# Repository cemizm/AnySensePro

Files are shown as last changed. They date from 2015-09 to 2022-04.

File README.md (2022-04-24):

# AnySense Pro
The AnySense Pro (aka 2.0) is an onboard flight logger and real-time telemetry system for (mainly) multicopters with versatile interfacing to various flight controllers, sensors and telemetry protocols. It is a further development of the [AnySense](https://github.com/cemizm/AnySense) and provides a more powerfull MCU (STM32F3) an SD-Card interface and USB connectivity for configuration and updates. A detailed description of the AnySense Pro can be found in the [manual](Dokumentation/AnySense_Pro_EN_.pdf) and in sources of the [main application](Firmware/shared/Application/source).

## Features
The aim of the AnySense Pro is to build a bridge between multiple proprietary systems and protocols in order to reduce the total take-off weight of the flight object. This is achived by reusing any existing sensor (source) of the integrated flight controller in a multicopter, and feeding the telemetry data to various sinks like the onboard SD-Card or real-time telemetrie return channel. 
 
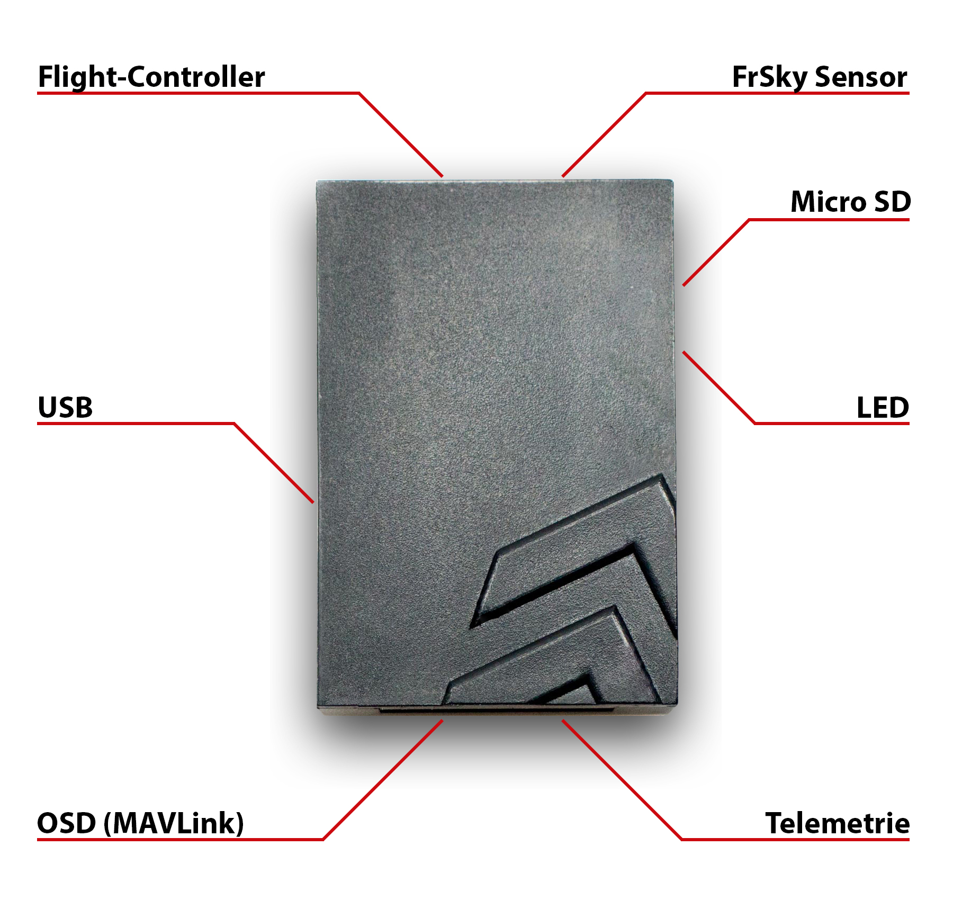
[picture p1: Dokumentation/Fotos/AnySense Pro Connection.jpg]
 

### Flight Controller (source)
The AnySense Pro supports a wide range of open source and commercial flight controllers. A full list of provided sensors of each flight controller can be found in the [Manual](Dokumentation/AnySense_Pro_EN_.pdf). The flight controller connector provides 5V power supply, a CAN-Bus interface and full-duplex uart interface. 

| | |
|:---:|:---:|
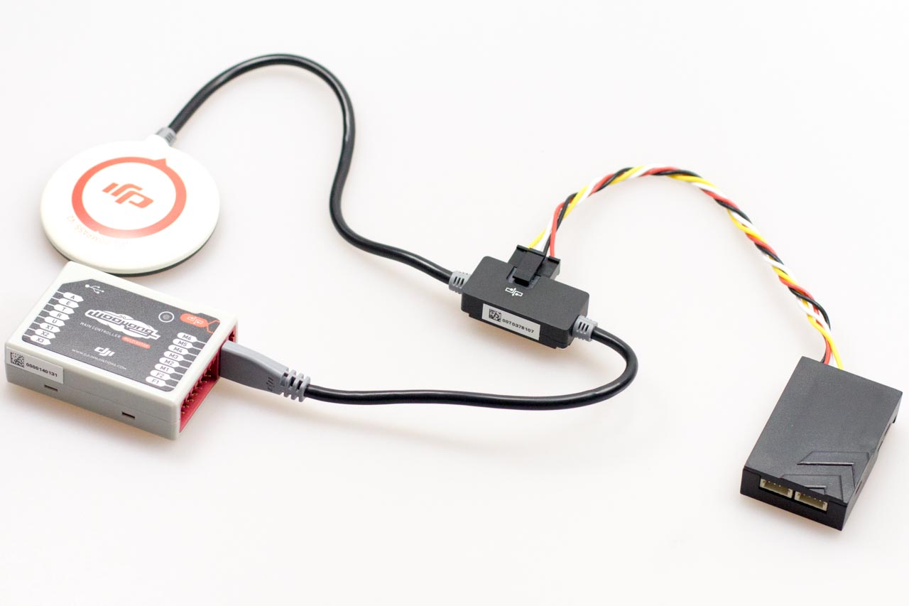
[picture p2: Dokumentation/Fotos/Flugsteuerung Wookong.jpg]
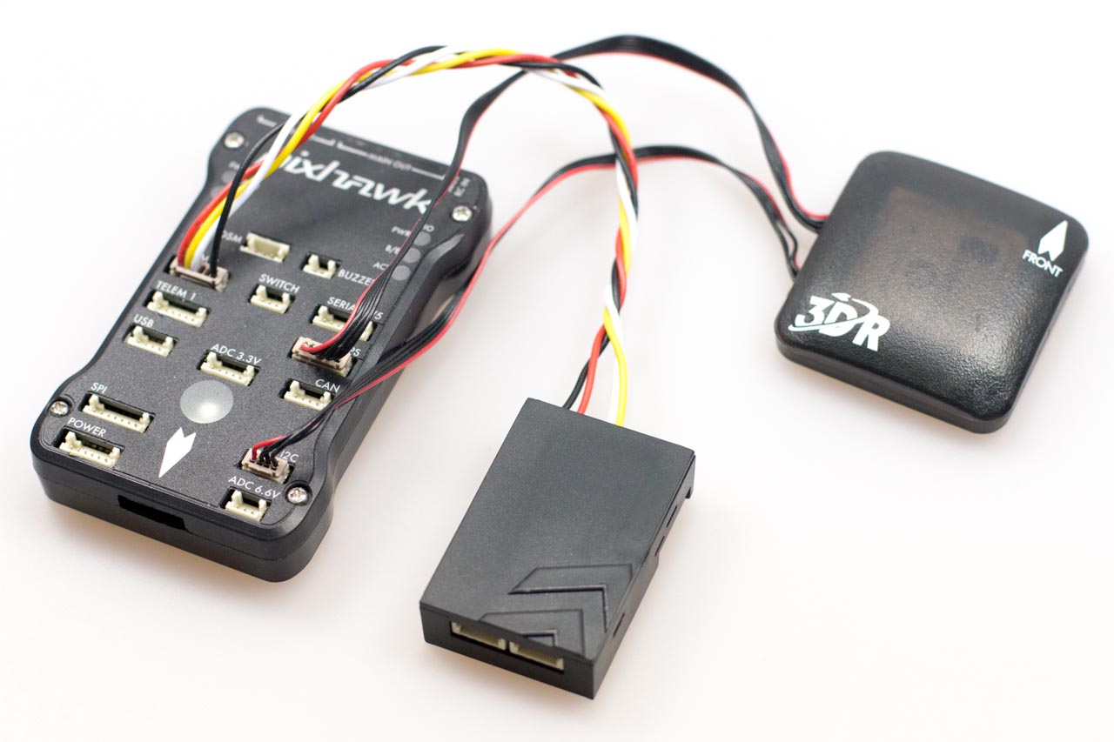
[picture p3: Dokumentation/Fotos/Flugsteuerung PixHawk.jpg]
|  |  |

* [DJI Naza-M V1 / Lite](https://www.dji.com/de/naza-m-lite/feature)
* [DJI Naza-M V2](https://www.dji.com/de/naza-m-v2)
* [DJI Wookong](https://www.dji.com/de/wookong-m)
* [DJI A2](https://www.dji.com/de/a2)
* [DJI Phantom 2](https://www.dji.com/de/phantom-2)
* [3DR Pixhawk](https://docs.px4.io/master/en/flight_controller/mro_pixhawk.html)
* [Tarot ZYX-M](http://www.tarotrc.com/Product/Detail.aspx?Lang=en&Id=65341cc3-7941-4a12-84ea-8abc58bd59e7)
* [Align MRS](https://www.align.com.tw/index.php/download-en/mrs/)

Depending on the flight control, a corresponding cable with connectors and pin assignment is required. The pin assignment defines which hardware interface is used. The pinout of the flight controller connector on the AnySense Pro can be found in the [Schematics](Hardware/Pro/AnySensePro.pdf) or in some [example cables](Hardware/Kabel/CANBusKabel.pdf).

### FrSky Sensor (source)
Additionally to the integrated sensor of the flight controller, it is possible to use sensor of the vendor FrSky to obtain further telemetry data like a current sensor to measure total current consumption or a cell voltage sensor to monitor individual cells of the battery pack. The full list of supported sensors and implementation details can be found in the [source code](Firmware/shared/Application/source/SensorFrSky.cpp).

| | |
|:---:|:---:|
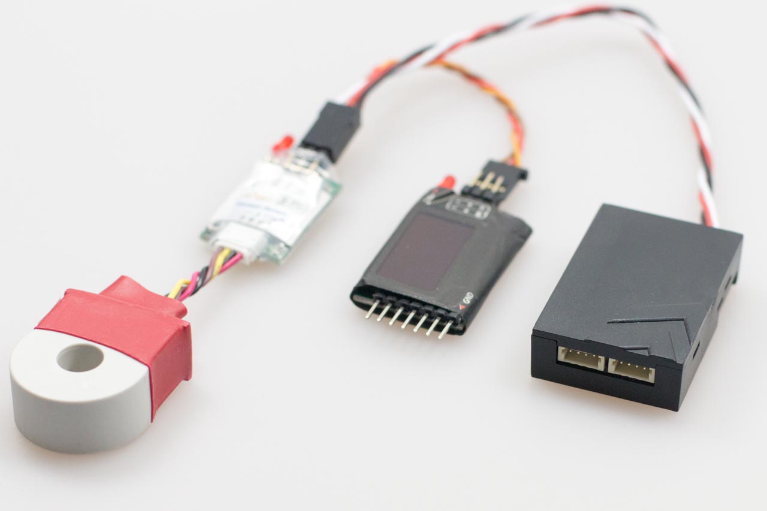
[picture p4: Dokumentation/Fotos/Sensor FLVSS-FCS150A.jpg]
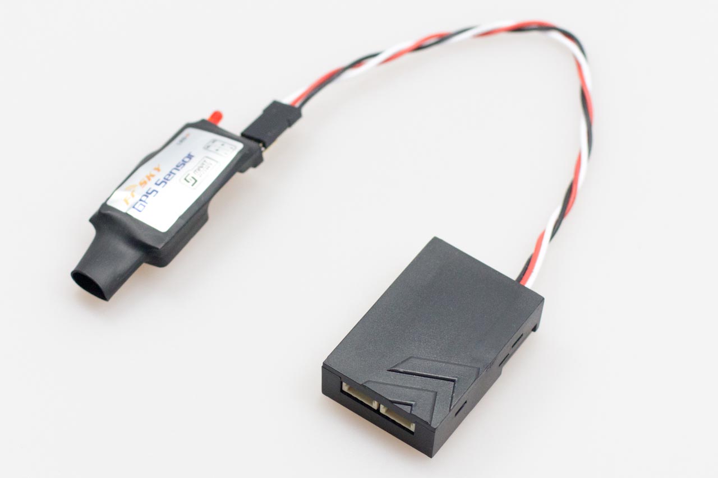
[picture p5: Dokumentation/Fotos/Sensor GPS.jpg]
|  |  |

The FrSky sensors run as a bus system and can therefore be daisy-chained together. for this purpose, each sensor offers two interconnected ports. The AnySense Pro acts as the master and each sensor operates as a slave. 

### USB
The USB interface of the AnySense Pro is used for configuration and firmware updates. The AnySense Pro implements an [USB-CDC device](Firmware/shared/Middleware/USB/source/USBCDCDevice.cpp) for serial communication with the host. The [host driver](Firmware/shared/driver/AnySensePro.inf) for the AnySense Pro uses [Microsoft provided in-box driver](https://docs.microsoft.com/en-us/windows-hardware/drivers/usbcon/usb-driver-installation-based-on-compatible-ids) with custom vendor and product ids. The AnySense Studio is a .NET WPF Application and can be used for configuration and firmware updates.
| | |
|:---:|:---:|
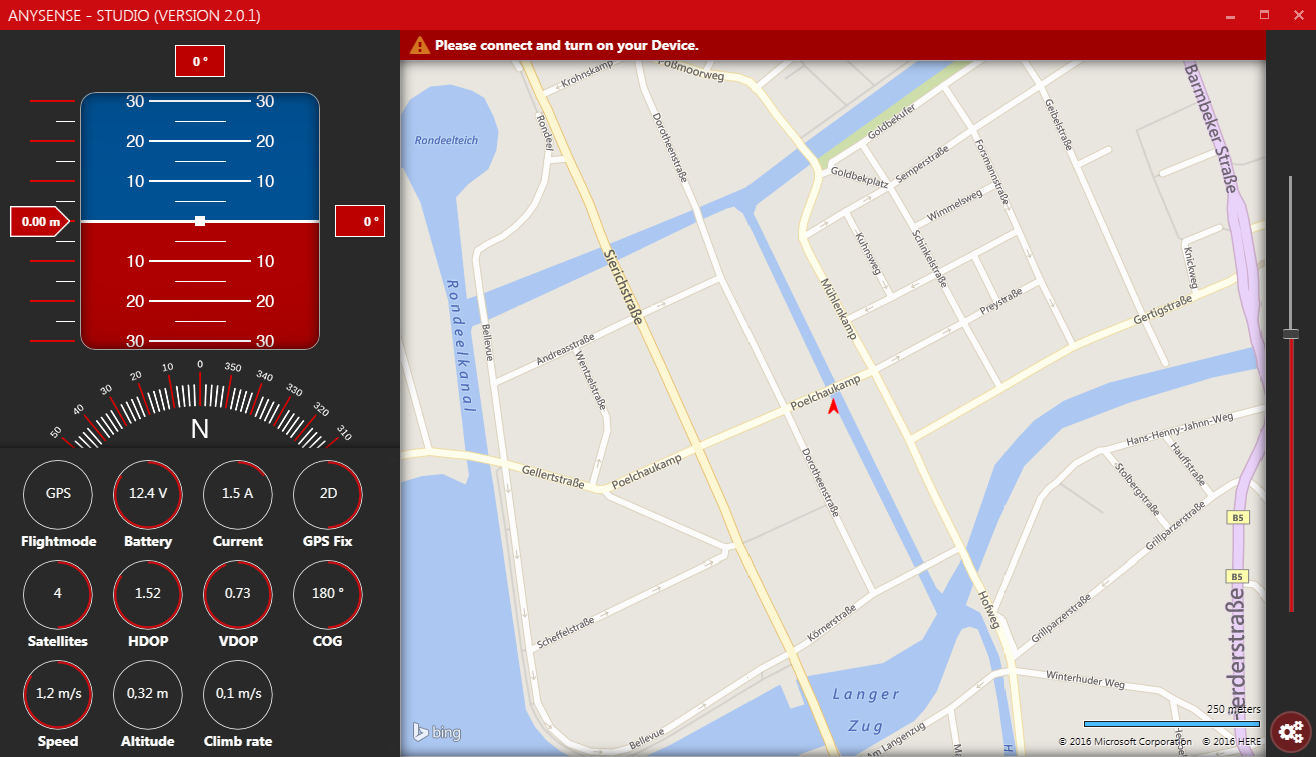
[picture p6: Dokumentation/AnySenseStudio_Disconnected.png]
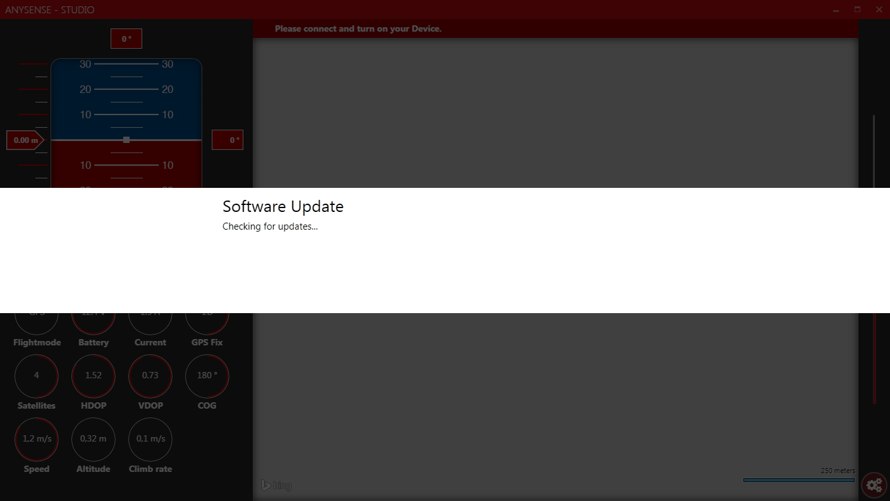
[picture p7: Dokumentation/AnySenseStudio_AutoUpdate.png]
|  |  |

### Micro SD (sink)

### Telemetry (sink)

### MAVLink OSD (sink)

## Project / Repository structure 

### Hardware
### Firmware
### GroundTools
### Dokumnetation

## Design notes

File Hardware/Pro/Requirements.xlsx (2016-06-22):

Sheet: Requirements
Function | IO
DJI | CAN Bus
Konfiguration | USB
Logging | SDIO
Telemetry | USART / I2C
FrSky Sensor | USART
Pixhawk | USART
MAVLink | USART

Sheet: STM32F303RET6
Pin | Name | Function 1 | Function 2 | Function 3 | Function 4
1 | VBAT
2 | PC13
3 | PC14-OSC32_IN
4 | PC15-OSC32_OUT
5 | PF0-OSC_IN | SPI2_NSS | I2C2_SDA |  |  | Function | IO | Mapped
6 | PF1- OSC_OUT | SPI2_SCK | I2C2_SCL |  |  | DJI | CAN Bus | x
7 | NRST |  |  |  |  | Konfiguration | USB | x
8 | PC0 |  |  |  |  | Logging | SPI | x
9 | PC1 |  |  |  |  | Telemetry | USART / I2C | x
10 | PC2 |  |  |  |  | FrSky Sensor | USART
11 | PC3 |  |  |  |  | Pixhawk | USART | x
12 | VSSA |  |  |  |  | MAVLink (OSD) | USART
13 | VDDA |  |  |  |  | Debug | SWD | x
14 | PA0 |  |  |  |  | Extension | i2C | x
15 | PA1 |  |  |  |  | Flash | SPI
16 | PA2 | USART2_TX |  |  |  | Bluetooth | SPI
17 | PA3 | USART2_RX
18 | VSS_4
19 | VDD_4
20 | PA4 | SPI1_NSS | SPI3_NSS
21 | PA5 | SPI1_SCK
22 | PA6 | SPI1_MISO
23 | PA7 | SPI1_MOSI
24 | PC4 | USART1_TX
25 | PC5 | USART1_RX
26 | PB0
27 | PB1
28 | PB2
29 | PB10 | USART3_TX
30 | PB11 | USART3_RX
31 | VSS_2
32 | VDD_2
33 | PB12 | SPI2_NSS
34 | PB13 | SPI2_SCK
35 | PB14 | SPI2_MISO
36 | PB15 | SPI2_MOSI
37 | PC6
38 | PC7
39 | PC8
40 | PC9 |  |  |  | I2C3_ SDA
41 | PA8 |  |  |  | I2C3_ SCL
42 | PA9 | USART1_TX |  |  | I2C2_SCL
43 | PA10 | USART1_RX | SPI2_MISO |  | I2C2_SDA
44 | PA11 | CAN_RX | SPI2_MOSI | USB_DM
45 | PA12 | CAN_TX |  | USB_DP
46 | PA13 | SWDIO-JTMS
47 | VSS_3
48 | VDD_3
49 | PA14 | SWCLK-JTCK | USART2_TX |  | I2C1_SDA
50 | PA15 | SPI1_NSS | USART2_RX | SPI3_NSS | I2C1_SCL
51 | PC10 | UART4_TX | USART3_TX | SPI3_SCK
52 | PC11 | UART4_RX | USART3_RX | SPI3_MISO
53 | PC12 | UART5_TX |  | SPI3_MOSI
54 | PD2 | UART5_RX
55 | PB3 | SPI1_SCK | SPI3_SCK | USART2_TX | JTDO-TRACESWO |  |  |  | uint8_t | 12 | 12
56 | PB4 | SPI1_MISO | SPI3_MISO | USART2_RX |  |  |  |  | float | 13 | 52
57 | PB5 | SPI1_MOSI | SPI3_MOSI |  | I2C3_SDA |  |  |  | double | 4 | 16
58 | PB6 | USART1_TX |  |  | I2C1_SCL |  |  |  | uint16_t | 42 | 84
59 | PB7 | USART1_RX |  |  | I2C1_SDA |  |  |  | uint32_t | 2 | 8
60 | BOOT0 |  |  |  |  |  |  |  |  |  | 172
61 | PB8 | USART3_RX | CAN_RX |  | I2C1_SCL
62 | PB9 | USART3_TX | CAN_TX |  | I2C1_SDA
63 | VSS_1
64 | VDD_1

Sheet: DMA
Channel | SPI | USART | I2C
DMA1_CHANNEL1 |  |  | I2C3_TX
DMA1_CHANNEL2 | SPI1_RX | USART3_TX | I2C3_RX | UART4 (OSD) | TX
DMA1_CHANNEL3 | SPI1_TX | USART3_RX |  | USART2 (FC) | TX,RX
DMA1_CHANNEL4 | SPI2_RX | USART1_TX | I2C2_TX | USART1 (Telemetry) | TX
DMA1_CHANNEL5 | SPI2_TX | USART1_RX | I2C2_RX | I2C2 (Telemetry) | TX
DMA1_CHANNEL6 |  | USART2_RX | I2C1_TX | SPI (MicroSD) | TX,RX
DMA1_CHANNEL7 |  | USART2_TX | I2C1_RX | SPI (Flash) | TX,RX
DMA2_CHANNEL1 | SPI3_RX |  |  | SPI (BLE) | TX,RX
DMA2_CHANNEL2 | SPI3_TX
DMA2_CHANNEL3 |  | UART4_RX
DMA2_CHANNEL4 | SPI4_RX
DMA2_CHANNEL5 | SPI4_TX | UART4_TX |  |  |  | 0 | PackGPS | 50
 |  |  |  |  |  | 1 | PackAttitude | 100
 |  |  |  |  |  | 2 | PackVFRHud | 150
 |  |  |  |  |  | 3 | PackRCOut | 200
 |  |  |  |  |  | 4 | PackAttitude | 250
 |  |  |  |  |  | 5 | PackBatteryPack | 300
 |  |  |  |  |  | 6 | PackHeartbeat | 350
 |  |  |  |  |  | 7 | PackRCOut | 400 | 1
 |  |  |  |  |  | 8 | PackAttitude | 450
 |  |  |  |  |  | 9 | PackSystemStatus | 500

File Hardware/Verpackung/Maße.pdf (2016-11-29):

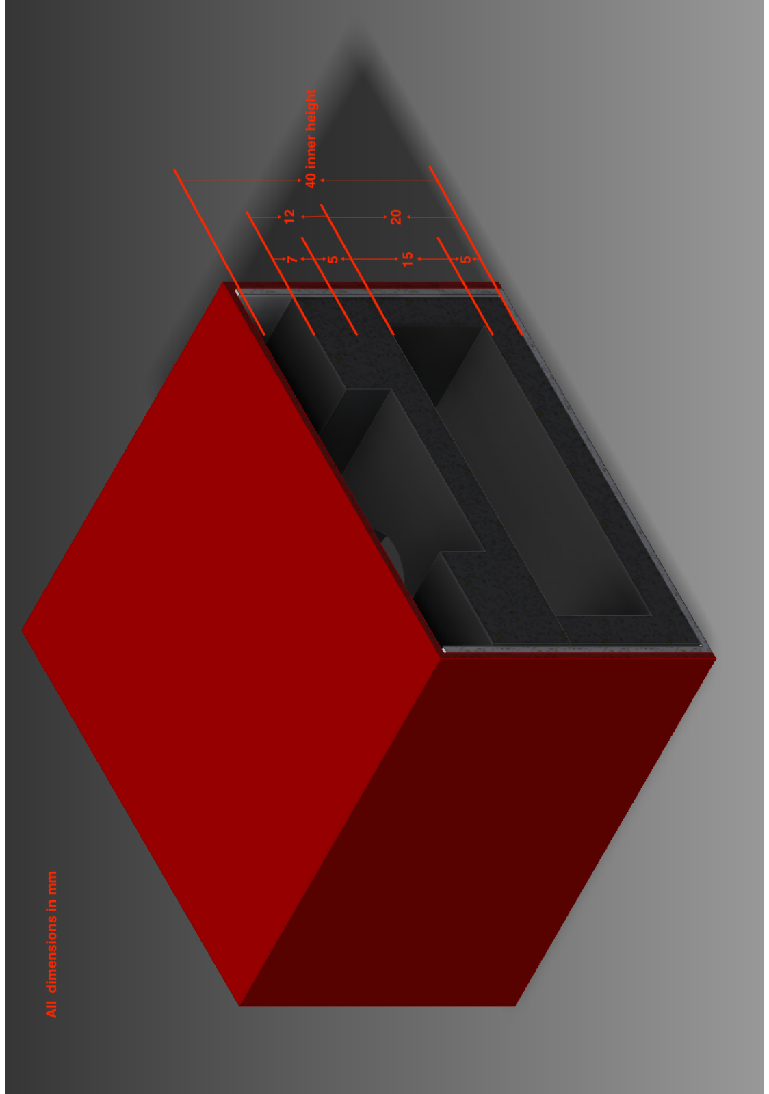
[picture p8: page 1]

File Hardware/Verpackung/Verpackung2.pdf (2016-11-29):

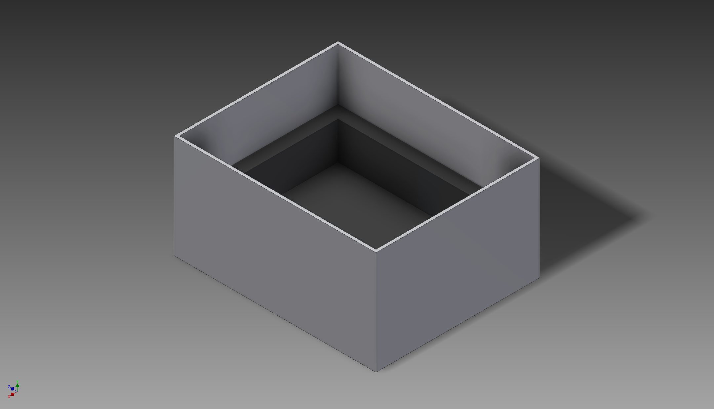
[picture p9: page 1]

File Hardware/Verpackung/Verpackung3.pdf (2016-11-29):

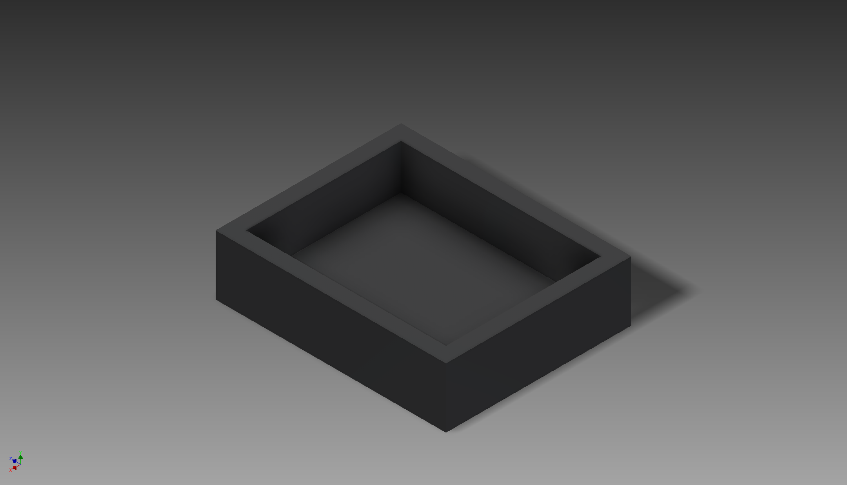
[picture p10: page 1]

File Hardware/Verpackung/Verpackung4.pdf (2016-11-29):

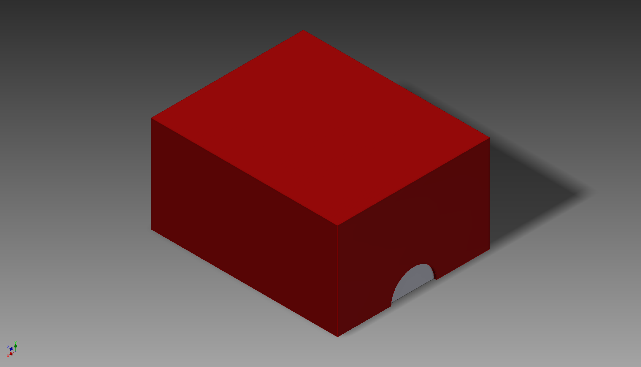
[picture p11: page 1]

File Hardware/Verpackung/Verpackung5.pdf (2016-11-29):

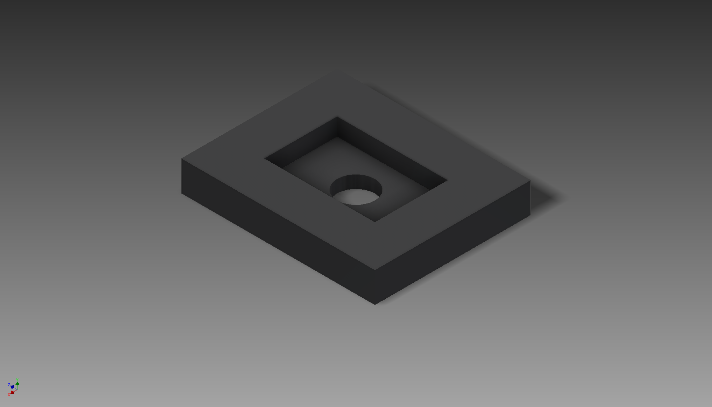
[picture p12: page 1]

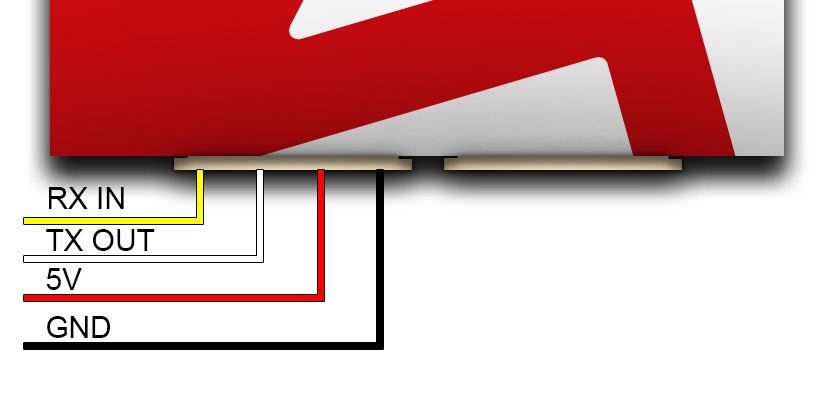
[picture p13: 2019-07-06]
Dokumentation/pinout.png

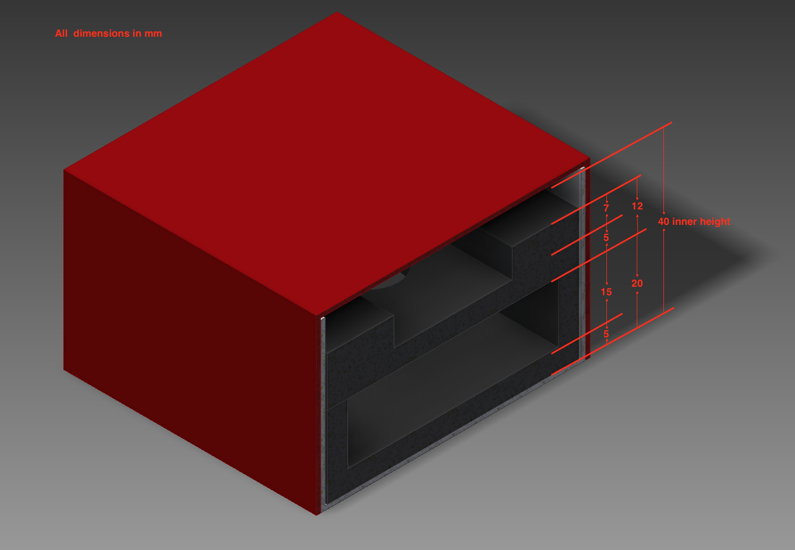
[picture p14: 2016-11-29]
Hardware/Verpackung/Maße.png

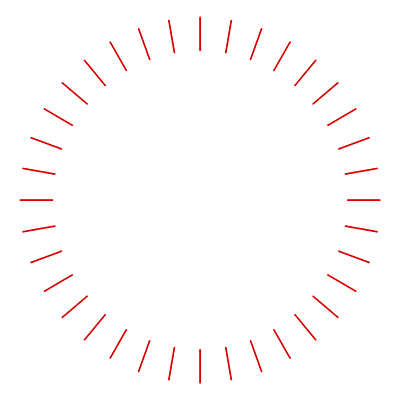
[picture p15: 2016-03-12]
GroundTools/xeniC.AnySense.KonfigurationManager/xeniC.AnySense.Controls/Images/compass.png

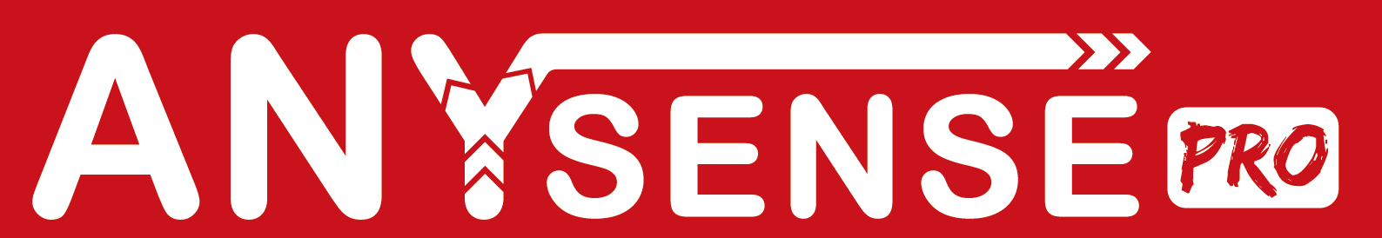
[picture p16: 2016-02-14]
GroundTools/xeniC.AnySense.KonfigurationManager/xeniC.AnySense.KonfigurationManager/Images/AnySense.png

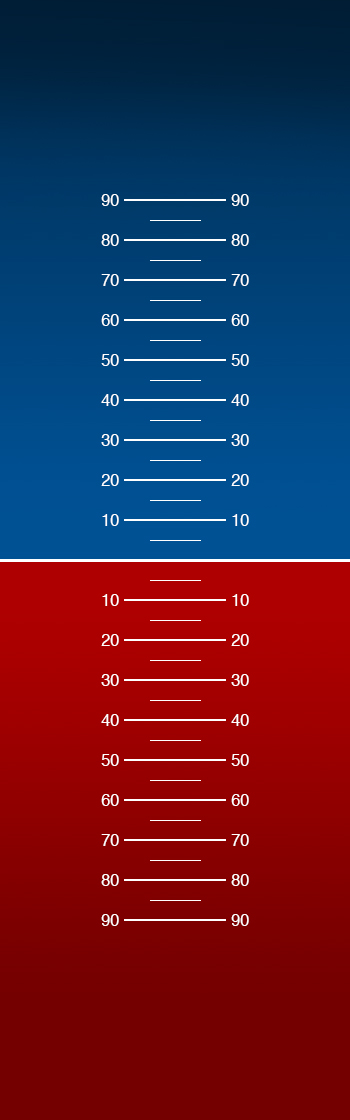
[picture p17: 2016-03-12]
GroundTools/xeniC.AnySense.KonfigurationManager/xeniC.AnySense.Controls/Images/horizon.jpg

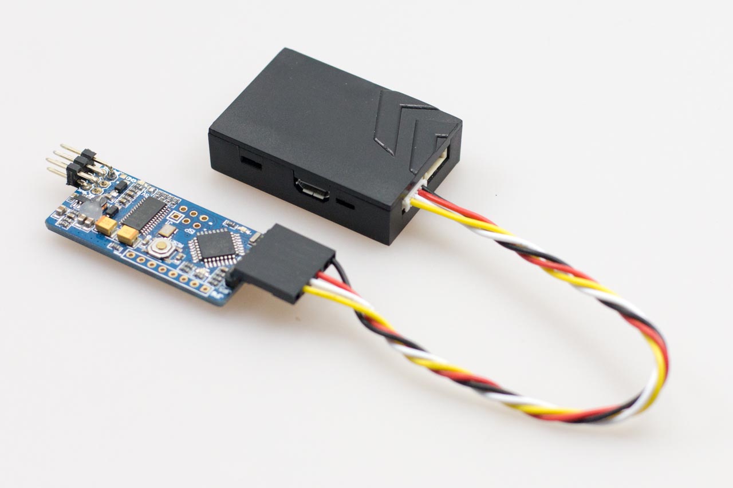
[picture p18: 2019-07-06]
Dokumentation/Fotos/OSD MinimOSD.jpg

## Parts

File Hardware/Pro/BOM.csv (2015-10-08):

Qty | Value | Device | Package | Parts | Description | MPN | OC_FARNELL | OC_NEWARK | PACKAGE | SUPPLIER
1 |  | LEDCHIP-LED0603 | CHIP-LED0603 | P | LED |  | 2468791RL
1 |  | LEDCHIP-LED0603 | CHIP-LED0603 | E | LED |  | 2468792RL
1 |  | LEDCHIP-LED0603 | CHIP-LED0603 | A | LED |  | 2468793RL
1 | 1.5K | R-EU_R0402 | R0402 | R4 | RESISTOR, European symbol |  | 2302739RL
7 | 100nF | C-EUC0402K | C0402K | C8, C12, C14, C15, C16, C30, C31 | CAPACITOR, European symbol |  | 1759380RL
5 | 10K | R-EU_R0402 | R0402 | R3, R5, R9, R10, R12 | RESISTOR, European symbol |  | 2302739RL
2 | 10nF | C-EUC0402K | C0402K | C6, C11 | CAPACITOR, European symbol |  | 1758924RL
1 | 15K | R-EU_R0402 | R0402 | R13 | RESISTOR, European symbol |  | 2302739RL
2 | 18pF | C-EUC0402K | C0402K | C9, C10 | CAPACITOR, European symbol |  | 1758947RL
1 | 1M | R-EU_R0402 | R0402 | R2 | RESISTOR, European symbol |  | 2302957RL
1 | 1uF | C-EUC0402K | C0402K | C7 | CAPACITOR, European symbol |  | 2320776RL
1 | 1uF | C-EUC0603K | C0603K | C1 | CAPACITOR, European symbol |  | 1759409RL
2 | 22R | R-EU_R0402 | R0402 | R1, R11 | RESISTOR, European symbol |  | 2302739RL
2 | 4.7uF | C-EUC0603K | C0603K | C13, C18 | CAPACITOR, European symbol |  | 2320818RL
3 | 820 | R-EU_R0402 | R0402 | R6, R7, R8 | RESISTOR, European symbol |  | 2302628RL
1 | ABM3B | ABM3B-8.000MHZ-B2-T | 5X3.2MM | Y1 |  |  | 2467818RL
2 | BAT721C | BAT721C | SOT23 | D1, D2 | Schottky Diodes |  | 1081199RL
1 | LP2992IM5-3.3 | LP2992IM5-3.3 | SOT-23 | U1 | Low-Dropout Regulator | LP2992IM5-3.3 | 1469141RL
1 | M25P16VMN6P | M25P16VMN6P | M25P16 | U6 |  |  | 1734973
1 | MEM2051-00-195-00-A | MEM2051-00-195-00-A | MEM2051 | X6 | GLOBAL CONNECTOR TECHNOLOGY MEM2051-00-195-00-A STECKPLATZ, MICRO-SD, 8POS, SMTHersteller: GLOBAL CONNECTOR TECHNOLOGYBestellnummer: 2443092Herstellerteilenummer: MEM2051-00-195-00-A |  | 2443092
3 | SM4B-ZR | SM4B-ZR | S4B-ZR-SM4 | OSD, SENSOR, TELEM | ZH Connector: 1.5mm pitch/Disconnectable Crimp style connector |  | 1830923
1 | SN65HVD232D | SN65HVD232D | SOIC127P600X175-8N | U3 | 3.3-V CAN TRANSCEIVERS | SN65HVD232D | 1103107 | 35K4890 | SOIC-8 | Texas Instruments
1 | STM32F303RET6 | STM32F303RET6 | LQFP64 | U4 | ARM® Cortex®-M4 32b MCU+FPU, up to 512KB Flash, 80KB SRAM, FMC, 4 ADCs, 2 DAC ch., 7 comp, 4 Op-Amp, 2.0-3.6 V |  | 2466939
1 | TC2030-IDC-NL | TC2030-IDC-NL | TC2030-IDC | X7
1 | X8B-ZR-SM4 | X8B-ZR-SM4 | S8B-ZR-SM4 | FC | JST ZH Connector |  | 1830925
1 | ZX62R-B-5PA(11) | ZX62R-B-5PA(11) | ZX62R-B-5PA(11) | USB | Micro USB Connector |  | 1645325

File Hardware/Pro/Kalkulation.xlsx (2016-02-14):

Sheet: Stückliste Proto
 |  |  |  |  |  |  | ab | 200 | Stück |  | ab | 500 | Stück
Qty | Farnell | Value | Device | Package | Parts | Description | Menge | Einzelpreis | Positionspreis | ohne BLE | Menge2 | Einzelpreis2 | Positionspreis2 | ohne BLE2 | Link
1 | 2468791RL |  | LEDCHIP-LED0603 | CHIP-LED0603 | P | LED, GRÜN, 3MCD, 570NM, SMD | 200 | 0.0764 € | 15.28 € | 15.28 € | 500 | 0.0634 € | 31.70 € | 31.70 € | Details
1 | 2468792RL |  | LEDCHIP-LED0603 | CHIP-LED0603 | E | LED, ROT, 22MCD, 630NM, SMD | 200 | 0.0712 € | 14.24 € | 14.24 € | 500 | 0.0585 € | 29.25 € | 29.25 € | Details
1 | 2468793RL |  | LEDCHIP-LED0603 | CHIP-LED0603 | A | LED, GELB, 10MCD, 590NM, SMD | 200 | 0.0712 € | 14.24 € | 14.24 € | 500 | 0.0585 € | 29.25 € | 29.25 € | Details
12 | 1759380RL | 100nF | C-EUC0402K | C0402K | C4, C5, C8, C12, C14, C15, C16, C23, C27, C29, C30, C31 | Keramikvielschichtkondensator, SMD, Baureihe MC, 0.1 µF, ± 10%, X5R, 10 V | 2400 | 0.0050 € | 12.00 € | 12.00 € | 6000 | 0.0020 € | 12.00 € | 12.00 € | Details
2 | 2320762RL | 100pF | C-EUC0402K | C0402K | C3, C24 | Keramikvielschichtkondensator, SMD, Baureihe MC, 100 pF, ± 10%, C0G / NP0, 50 V | 400 | 0.0060 € | 2.40 € |  | 1000 | 0.0050 € | 5.00 € |  | Details
6 | 2302739RL | 10K | R-EU_R0402 | R0402 | R1, R3, R4, R5, R9, R10 | Dickschichtwiderstand, Oberflächenmont., Baureihe AEC-Q200 ERJ, 10 kohm, 100 mW, ± 1%, 50 V | 1200 | 0.0069 € | 8.28 € | 8.28 € | 3000 | 0.0059 € | 17.70 € | 17.70 € | Details
2 | 1758924RL | 10nF | C-EUC0402K | C0402K | C6, C11 | Keramikvielschichtkondensator, SMD, Baureihe MC, 0.01 µF, ± 10%, X7R, 25 V | 400 | 0.0070 € | 2.80 € | 2.80 € | 1000 | 0.0060 € | 6.00 € | 6.00 € | Details
1 | 2470467RL | 150nF | C-EUC0402K | C0402K | C25 | Keramikvielschichtkondensator, SMD, Baureihe GRM, 0.15 µF, ± 10%, X7R, 16 V | 200 | 0.0278 € | 5.56 € |  | 500 | 0.0181 € | 9.05 € |  | Details
2 | 1758945RL | 15pF | C-EUC0402K | C0402K | C17, C19 | Keramikvielschichtkondensator, SMD, Baureihe MC, 15 pF, ± 5%, C0G / NP0, 50 V | 400 | 0.0060 € | 2.40 € |  | 1000 | 0.0050 € | 5.00 € |  | Details
2 | 1758947RL | 18pF | C-EUC0402K | C0402K | C9, C10 | Keramikvielschichtkondensator, SMD, Baureihe MC, 18 pF, ± 5%, C0G / NP0, 50 V | 400 | 0.0060 € | 2.40 € | 2.40 € | 1000 | 0.0050 € | 5.00 € | 5.00 € | Details
1 | 2302957RL | 1M | R-EU_R0402 | R0402 | R2 | Dickschichtwiderstand, Oberflächenmont., Baureihe AEC-Q200 ERJ, 1 Mohm, 100 mW, ± 1%, 50 V | 200 | 0.0104 € | 2.08 € |  | 500 | 0.0069 € | 3.45 € |  | Details
6 | 2362093RL | 1uF | C-EUC0402K | C0402K | C1, C2, C7, C22, C26, C28 | Keramikvielschichtkondensator, SMD, Baureihe GRM, 1 µF, ± 10%, X5R, 16 V, 0402 | 1200 | 0.0212 € | 25.44 € |  | 3000 | 0.0149 € | 44.70 € |  | Details
2 | 1758951RL | 22pF | C-EUC0402K | C0402K | C20, C21 | Keramikvielschichtkondensator, SMD, Baureihe MC, 22 pF, ± 5%, C0G / NP0, 50 V | 400 | 0.0060 € | 2.40 € |  | 1000 | 0.0050 € | 5.00 € |  | Details
1 | 1885496RL | 2450AT18A100 | 2450AT18A100 | 2450AT18A100E | A1 | JOHANSON TECHNOLOGY 2450AT18A100E ANTENNE, KERAMIK, 2.45GHZ | 200 | 0.3190 € | 63.80 € |  | 500 | 0.2850 € | 142.50 € |  | Details
2 | 2426952RL | 4.7uF | C-EUC0402K | C0402K | C13, C18 | Keramikvielschichtkondensator, SMD, Baureihe GRM, 4.7 µF, ± 20%, X5R, 6.3 V | 400 | 0.0816 € | 32.64 € | 32.64 € | 1000 | 0.0576 € | 57.60 € | 57.60 € | Details
3 | 2302628RL | 820 | R-EU_R0402 | R0402 | R6, R7, R8 | Dickschichtwiderstand, Oberflächenmont., Baureihe AEC-Q200 ERJ, 820 ohm, 100 mW, ± 1%, 50 V | 600 | 0.0069 € | 4.14 € | 4.14 € | 1500 | 0.0069 € | 10.35 € | 10.35 € | Details
1 | 2467818RL | ABM3B | ABM3B-8.000MHZ-B2-T | 5X3.2MM | Y1 | CRYSTAL, 8MHZ, 18PF, 5 X 3.2MM | 200 | 0.6740 € | 134.80 € | 134.80 € | 500 | 0.5980 € | 299.00 € | 299.00 € | Details
1 | 2467830RL | ABM8 | ABM8-16.000MHZ-10-1-U-T | 3.2X2.5MM | Y2 | QUARZ, 16MHZ, 10PF, 3.2 X 2.5MM | 200 | 0.6360 € | 127.20 € |  | 500 | 0.5730 € | 286.50 € |  | Details
1 | 2467865RL | ABS07 | ABS.ABS07 | ABS07 | Y3 | QUARZ, 32.768KHZ, 12.5PF, 3.2 X 1.5MM | 200 | 0.7890 € | 157.80 € |  | 500 | 0.7120 € | 356.00 € |  | Details
1 | 2454731RL | BALF-NRG-01D3 | BALF-NRG-01D3 | BALF-NRG-01D3 | U5 | FILTER, MATCH, BLUETOOTH, 2.4GHZ-2.5GHZ | 200 | 0.2200 € | 44.00 € |  | 500 | 0.1790 € | 89.50 € |  | Details
2 | 1081199RL | BAT721C | BAT721C | SOT23 | D1, D2 | Kleinsignal-Schottky-Diode, Zweifach, gemeinsame Kathode, 40 V, 200 mA, 300 mV, 1 A, 125 °C | 400 | 0.0773 € | 30.92 € | 30.92 € | 1000 | 0.0751 € | 75.10 € | 75.10 € | Details
1 | 2460183RL | BLUENRGQTR | BLUENRGQTR | QFN32 | U2 | HF-TRANSCEIVER, 2.4835GHZ-2.4GHZ, QFN-32 | 200 | 2.5100 € | 502.00 € |  | 500 | 1.9700 € | 985.00 € |  | Details
1 | 1469141RL | LP2992IM5-3.3 | LP2992IM5-3.3 | SOT-23 | U1 | SPANNUNGSREGLER,LINEAR, 3.3V,SMD | 200 | 0.5830 € | 116.60 € | 116.60 € | 500 | 0.4850 € | 242.50 € | 242.50 € | Details
1 | 1734973 | M25P16VMN6P | M25P16VMN6P | M25P16 | U6 | SPEICHER, FLASH, SERIAL, 16MBIT, 8NSOIC | 200 | 0.8150 € | 163.00 € | 163.00 € | 500 | 0.7020 € | 351.00 € | 351.00 € | Details
1 | 2443092 | MEM2051-00-195-00-A | MEM2051-00-195-00-A | MEM2051 | X6 | STECKPLATZ, MICRO-SD, 8POS, SMT | 200 | 0.8040 € | 160.80 € | 160.80 € | 500 | 0.6720 € | 336.00 € | 336.00 € | Details
3 | 1830923 | SM4B-ZR | SM4B-ZR | S4B-ZR-SM4 | OSD, SENSOR, TELEMETRY | STECKER,ZH,SIDE,4KONT,1.5MM,SMT | 600 | 0.2610 € | 156.60 € | 156.60 € | 1500 | 0.2360 € | 354.00 € | 354.00 € | Details
1 | 1103107 | SN65HVD232D | SN65HVD232D | SOIC127P600X175-8N | U3 | CAN-Bus, Transceiver, CAN, 1, 1, 3 V, 3.6 V, SOIC | 200 | 1.2200 € | 244.00 € | 244.00 € | 500 | 0.8660 € | 433.00 € | 433.00 € | Details
1 | 2466939 | STM32F303RET6 | STM32F303RET6 | LQFP64 | U4 | MCU, 32BIT, CORTEX-M4, 72MHZ, LQFP-64 | 200 | 5.7900 € | 1158.00 € | 1158.00 € | 500 | 4.8700 € | 2435.00 € | 2435.00 € | Details
1 |  | TC2030-IDC-NL | TC2030-IDC-NL | TC2030-IDC | X7 |  | 200 |  | 0.00 € | 0.00 € | 500 |  | 0.00 € | 0.00 € | Details
1 | 1830925 | X8B-ZR-SM4 | X8B-ZR-SM4 | S8B-ZR-SM4 | FC | STECKER,ZH,SIDE,8KONT,1.5MM,SMT | 200 | 0.7350 € | 147.00 € | 147.00 € | 500 | 0.4880 € | 244.00 € | 244.00 € | Details
1 | 1645325 | ZX62R-B-5PA(11) | ZX62R-B-5PA(11) | ZX62R-B-5PA(11) | USB | MICRO USB 2.0 BUCHSE, TYP B, SMD | 200 | 0.4060 € | 81.20 € | 81.20 € | 500 | 0.3620 € | 181.00 € | 181.00 € | Details
Ergebnis |  |  |  |  |  |  |  | 17.1701 | 3434.02 € | 12.49 € |  | 14.1623 | 7081.15 € | 10.30 € | 0.0514945

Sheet: Stückliste Proto2
Kleinteile |  |  |  |  |  |  | Ab | 200 |  | ab | 500
Qty | Farnell | Value | Package | Parts | Description | Link | Anzahl | EP | Summe | Offen | Anzahl2 | EP2 | Summe2 | Offen2
1 | 2468791RL |  | CHIP-LED0603 | P | LED Green | Details | 200 | 0.0634 € | 12.68 € |  | 500 | 0.0634 € | 31.70 €
1 | 2468792RL |  | CHIP-LED0603 | E | LED Red | Details | 200 | 0.0585 € | 11.70 € |  | 500 | 0.0585 € | 29.25 €
1 | 2468793RL |  | CHIP-LED0603 | A | LED Orange | Details | 200 | 0.0585 € | 11.70 € |  | 500 | 0.0585 € | 29.25 €
1 | 2302656RL | 1.5K | R0402 | R4 | Dickschichtwiderstand, Oberflächenmont., Baureihe AEC-Q200 ERJ, 1.5 kohm, 100 mW, ± 1%, 50 V | Details | 200 | 0.0069 € | 1.38 € |  | 500 | 0.0069 € | 3.45 €
7 | 1759380RL | 100nF | C0402K | C8, C12, C14, C15, C16, C30, C31 | Keramikvielschichtkondensator, SMD, Baureihe MC, 0.1 µF, ± 10%, X5R, 10 V | Details | 1400 | 0.0020 € | 2.80 € |  | 3500 | 0.0020 € | 7.00 €
5 | 2302739RL | 10K | R0402 | R3, R5, R9, R10, R12 | Dickschichtwiderstand, Oberflächenmont., Baureihe AEC-Q200 ERJ, 10 kohm, 100 mW, ± 1%, 50 V | Details | 1000 | 0.0059 € | 5.90 € |  | 2500 | 0.0059 € | 14.75 €
2 | 1758924RL | 10nF | C0402K | C6, C11 | Keramikvielschichtkondensator, SMD, Baureihe MC, 0.01 µF, ± 10%, X7R, 25 V | Details | 400 | 0.0060 € | 2.40 € |  | 1000 | 0.0060 € | 6.00 €
1 | 2302754RL | 15K | R0402 | R13 | Dickschichtwiderstand, Oberflächenmont., Baureihe AEC-Q200 ERJ, 15 kohm, 100 mW, ± 1%, 50 V | Details | 200 | 0.0050 € | 1.00 € |  | 500 | 0.0050 € | 2.50 €
2 | 1758947RL | 18pF | C0402K | C9, C10 | Keramikvielschichtkondensator, SMD, Baureihe MC, 18 pF, ± 5%, C0G / NP0, 50 V | Details | 400 | 0.0050 € | 2.00 € |  | 1000 | 0.0050 € | 5.00 €
1 | 2302957RL | 1M | R0402 | R2 | Dickschichtwiderstand, Oberflächenmont., Baureihe AEC-Q200 ERJ, 1 Mohm, 100 mW, ± 1%, 50 V | Details | 200 | 0.0069 € | 1.38 € |  | 500 | 0.0069 € | 3.45 €
1 | 2320776RL | 1uF | C0402K | C7 | Keramikvielschichtkondensator, SMD, Baureihe MC, 1 µF, ± 10%, X5R, 10 V | Details | 200 | 0.0140 € | 2.80 € |  | 500 | 0.0140 € | 7.00 €
1 | 1759409RL | 1uF | C0603K | C1 | Keramikvielschichtkondensator, SMD, Baureihe MC, 1 µF, ± 10%, X5R, 25 V | Details | 200 | 0.0170 € | 3.40 € |  | 500 | 0.0170 € | 8.50 €
2 | 2302453RL | 22R | R0402 | R1, R11 | Dickschichtwiderstand, Oberflächenmont., Baureihe AEC-Q200 ERJ, 22 ohm, 100 mW, ± 1%, 50 V | Details | 400 | 0.0069 € | 2.76 € |  | 1000 | 0.0069 € | 6.90 €
2 | 2320818RL | 4.7uF | C0603K | C13, C18 | Keramikvielschichtkondensator, SMD, Baureihe MC, 4.7 µF, ± 10%, X5R, 10 V | Details | 400 | 0.0440 € | 17.60 € |  | 1000 | 0.0440 € | 44.00 €
3 | 2302628RL | 820R | R0402 | R6, R7, R8 | Dickschichtwiderstand, Oberflächenmont., Baureihe AEC-Q200 ERJ, 820 ohm, 100 mW, ± 1%, 50 V | Details | 600 | 0.0069 € | 4.14 € |  | 1500 | 0.0069 € | 10.35 €
1 | 2467818RL | ABM3B | 5X3.2MM | Y1 | CRYSTAL, 8MHZ, 18PF, 5 X 3.2MM | Details | 200 | 0.5980 € | 119.60 € |  | 500 | 0.5980 € | 299.00 €
2 | 1081199RL | BAT721C | SOT23 | D1, D2 | Kleinsignal-Schottky-Diode, Zweifach, gemeinsame Kathode, 40 V, 200 mA, 300 mV, 1 A, 125 °C | Details | 400 | 0.0751 € | 30.04 € |  | 1000 | 0.0751 € | 75.10 €
 |  |  |  |  |  |  |  | 1.1664 | 233.28 € |  |  | 1.17 € | 583.20 €
Bauteile
Qty | Farnell | Value | Package | Parts | Description | Link | Anzahl | EP | Summe | Offen | Anzahl2 | EP2 | Summe2 | Offen2
1 | 1469141RL | LP2992IM5-3.3 | SOT-23 | U1 | SPANNUNGSREGLER,LINEAR, 3.3V,SMD | Details | 200 | 0.4850 € | 97.00 € |  | 500 | 0.4850 € | 242.50 €
1 | 1734973 | M25P16VMN6P | M25P16 | U6 | SPEICHER, FLASH, SERIAL, 16MBIT, 8NSOIC | Details | 200 | 0.7020 € | 140.40 € |  | 500 | 0.7020 € | 351.00 €
1 | 2443092 | MEM2051-00-195-00-A | MEM2051 | X6 | STECKPLATZ, MICRO-SD, 8POS, SMT | Details | 200 | 0.6720 € | 134.40 € |  | 500 | 0.6720 € | 336.00 €
1 | 1103107 | SN65HVD232D | SOIC127P600X175-8N | U3 | CAN-Bus, Transceiver, CAN, 1, 1, 3 V, 3.6 V, SOIC | Details | 200 | 0.8660 € | 173.20 € |  | 500 | 0.8660 € | 433.00 €
1 | 2466939 | STM32F303RET6 | LQFP64 | U4 | MCU, 32BIT, CORTEX-M4, 72MHZ, LQFP-64 | Details | 200 | 4.8700 € | 974.00 € | 214.28 € | 500 | 4.8700 € | 2435.00 €
1 | 1645325 | ZX62R-B-5PA(11) | ZX62R-B-5PA(11) | USB | MICRO USB 2.0 BUCHSE, TYP B, SMD | Details | 200 | 0.3620 € | 72.40 € |  | 500 | 0.3620 € | 181.00 €
3 |  | SM4B-ZR | S4B-ZR-SM4 | OSD, SENSOR, TELEM | STECKER,ZH,SIDE,4KONT,1.5MM,SMT | Details | 600 | 0.0550 € | 33.00 € |  | 1500 | 0.0550 € | 82.50 €
1 |  | S8B-ZR-SM4 | S8B-ZR-SM4 | FC | STECKER,ZH,SIDE,8KONT,1.5MM,SMT | Details | 200 | 0.0900 € | 18.00 € |  | 500 | 0.0900 € | 45.00 €
Ergebnis |  |  |  |  |  |  |  | 8.212 | 1642.40 € | 214.28 € |  | 8.212 | 4106.00 €
Total
Qty | Farnell | Value | Package | Parts | Description | Link | Anzahl | EP | Summe | Offen | Anzahl2 | EP2 | Summe2 | Offen2
1 |  |  |  |  | Platinen |  | 200 | 0.8633 € | 172.67 € | 172.67 € | 500 | 0.8633 € | 431.67 € | 431.67 €
1 |  |  |  |  | IC's |  | 200 | 8.2120 € | 1642.40 € | 214.28 € | 500 | 8.2120 € | 4106.00 €
1 |  |  |  |  | Bestückung |  | 200 | 5.4000 € | 1080.00 € | 1080.00 € | 500 | 4.7500 € | 2375.00 € | 2375.00 €
1 |  |  |  |  | Bestückung Einmalig |  | 200 | 1.3750 € | 275.00 € | 275.00 € | 500 | 0.5500 € | 275.00 € | 275.00 €
1 |  |  |  |  | Bestückung pro Abruf |  | 200 | 0.4750 € | 95.00 € | 95.00 € | 500 | 0.1900 € | 95.00 € | 95.00 €
1 |  |  |  |  | MicroSD Karte |  | 200 | 2.9500 € | 590.00 € | 590.00 € | 500 | 2.9500 € | 1475.00 € | 1475.00 €
1 |  |  |  |  | Gehäuse |  | 200 | 1.5000 € | 300.00 € | 300.00 € | 500 | 1.5000 € | 750.00 € | 750.00 €
1 |  |  |  |  | USB Kabel |  | 200 | 0.2900 € | 58.00 € |  | 500 | 0.2900 € | 145.00 €
1 |  |  |  |  | USB MicroSD Leser |  | 200 | 0.1940 € | 38.80 € |  | 500 | 0.1940 € | 97.00 €
1 |  |  |  |  | Telemetry Kabel |  | 200 | 0.1800 € | 36.00 € |  | 500 | 0.1800 € | 90.00 €
1 |  |  |  |  | CAN Bus Kabel |  | 200 | 0.2300 € | 46.00 € |  | 500 | 0.2300 € | 115.00 € | 115.00 €
1 |  |  |  |  | Verpackung |  | 200 | 0.7500 € | 150.00 € | 150.00 € | 500 | 0.7500 € | 375.00 € | 375.00 €
Ergebnis |  |  |  |  |  |  |  | 22.41933333 | 4483.87 € | 2876.95 € |  | 20.65933333 | 10329.67 € | 5891.67 €

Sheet: Bestücken
Spalte1 | Spalte2 | Spalte3 | Spalte4 | Spalte5 | Spalte6 | Reel
1 | 2468791RL | P |  | LEDCHIP-LED0603 | LED Green | 8
1 | 2468792RL | E |  | LEDCHIP-LED0603 | LED Red | 8
1 | 2468793RL | A |  | LEDCHIP-LED0603 | LED Orange | 8
1 | 2302656RL | R4 | 1.5K | R-EU_R0402 | Dickschichtwiderstand, Oberflächenmont., Baureihe AEC-Q200 ERJ, 1.5 kohm, 100 mW, ± 1%, 50 V | 8
7 | 1759380RL | C8, C12, C14, C15, C16, C30, C31 | 100nF | C-EUC0402K | Keramikvielschichtkondensator, SMD, Baureihe MC, 0.1 µF, ± 10%, X5R, 10 V | 8
5 | 2302739RL | R3, R5, R9, R10, R12 | 10K | R-EU_R0402 | Dickschichtwiderstand, Oberflächenmont., Baureihe AEC-Q200 ERJ, 10 kohm, 100 mW, ± 1%, 50 V | 8
2 | 1758924RL | C6, C11 | 10nF | C-EUC0402K | Keramikvielschichtkondensator, SMD, Baureihe MC, 0.01 µF, ± 10%, X7R, 25 V | 8
1 | 2302754RL | R13 | 15K | R-EU_R0402 | Dickschichtwiderstand, Oberflächenmont., Baureihe AEC-Q200 ERJ, 15 kohm, 100 mW, ± 1%, 50 V | 8
2 | 1758947RL | C9, C10 | 18pF | C-EUC0402K | Keramikvielschichtkondensator, SMD, Baureihe MC, 18 pF, ± 5%, C0G / NP0, 50 V | 8
1 | 2302957RL | R2 | 1M | R-EU_R0402 | Dickschichtwiderstand, Oberflächenmont., Baureihe AEC-Q200 ERJ, 1 Mohm, 100 mW, ± 1%, 50 V | 8
1 | 2320776RL | C7 | 1uF | C-EUC0402K | Keramikvielschichtkondensator, SMD, Baureihe MC, 1 µF, ± 10%, X5R, 10 V | 8
1 | 1759409RL | C1 | 1uF | C-EUC0603K | Keramikvielschichtkondensator, SMD, Baureihe MC, 1 µF, ± 10%, X5R, 25 V | 8
2 | 2302453RL | R1, R11 | 22R | R-EU_R0402 | Dickschichtwiderstand, Oberflächenmont., Baureihe AEC-Q200 ERJ, 22 ohm, 100 mW, ± 1%, 50 V | 8
2 | 2320818RL | C13, C18 | 4.7uF | C-EUC0603K | Keramikvielschichtkondensator, SMD, Baureihe MC, 4.7 µF, ± 10%, X5R, 10 V | 8
3 | 2302628RL | R6, R7, R8 | 820R | R-EU_R0402 | Dickschichtwiderstand, Oberflächenmont., Baureihe AEC-Q200 ERJ, 820 ohm, 100 mW, ± 1%, 50 V | 8
1 | 2467818RL | Y1 | ABM3B | ABM3B-8.000MHZ-B2-T | CRYSTAL, 8MHZ, 18PF, 5 X 3.2MM | 12
2 | 1081199RL | D1, D2 | BAT721C | BAT721C | Kleinsignal-Schottky-Diode, Zweifach, gemeinsame Kathode, 40 V, 200 mA, 300 mV, 1 A, 125 °C
1 | 1469141RL | U1 | LP2992IM5-3.3 | LP2992IM5-3.3 | SPANNUNGSREGLER,LINEAR, 3.3V,SMD | 8
1 | 1734973 | U6 | M25P16VMN6P | M25P16VMN6P | SPEICHER, FLASH, SERIAL, 16MBIT, 8NSOIC | Stick
1 | 2443092 | X6 | MEM2051-00-195-00-A | MEM2051-00-195-00-A | STECKPLATZ, MICRO-SD, 8POS, SMT | 24
3 | 1830923 | OSD, SENSOR, TELEM | SM4B-ZR | SM4B-ZR | STECKER,ZH,SIDE,4KONT,1.5MM,SMT | 24
1 | 1103107 | U3 | SN65HVD232D | SN65HVD232D | CAN-Bus, Transceiver, CAN, 1, 1, 3 V, 3.6 V, SOIC | Stick
1 | 2466939 | U4 | STM32F303RET6 | STM32F303RET6 | MCU, 32BIT, CORTEX-M4, 72MHZ, LQFP-64 | Tray
1 | 1830925 | FC | X8B-ZR-SM4 | X8B-ZR-SM4 | STECKER,ZH,SIDE,8KONT,1.5MM,SMT | 24
1 | 1645325 | USB | ZX62R-B-5PA(11) | ZX62R-B-5PA(11) | MICRO USB 2.0 BUCHSE, TYP B, SMD | 24

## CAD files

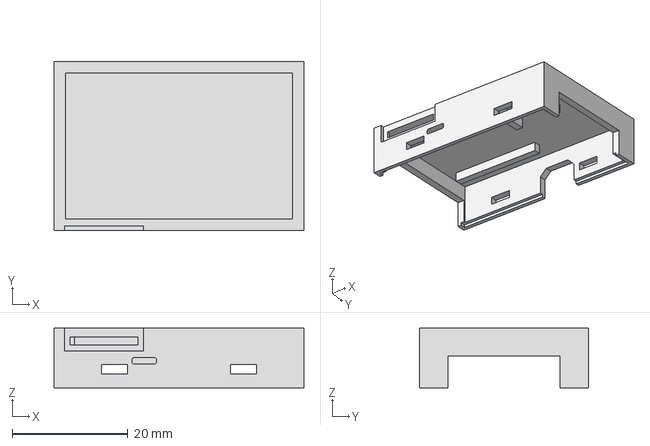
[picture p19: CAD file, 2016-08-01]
Hardware/Gehaeuse/Boden.stp
43.2 x 29.2 x 10.3 mm

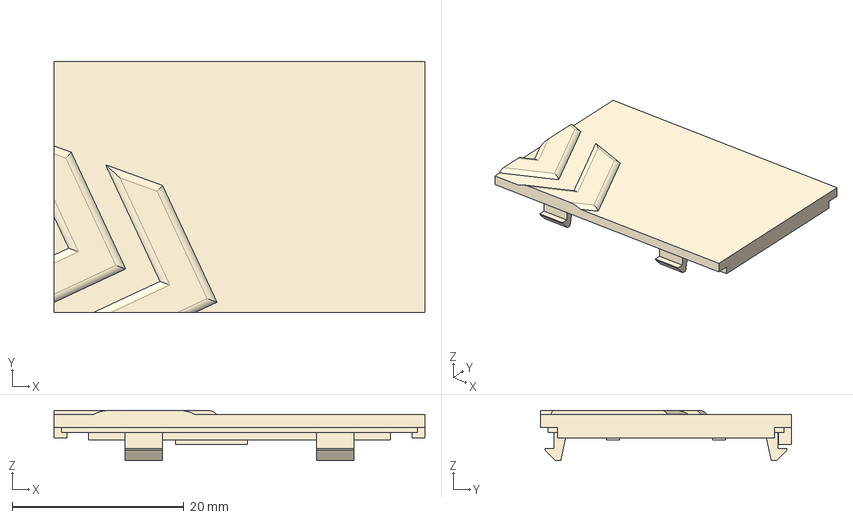
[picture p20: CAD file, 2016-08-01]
Hardware/Gehaeuse/Deckel.stp
43.2 x 29.2 x 5.85 mm

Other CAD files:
Hardware/Gehaeuse/Boden.ipt
Hardware/Gehaeuse/Boden.stl
Hardware/Gehaeuse/Deckel.ipt
Hardware/Gehaeuse/Deckel.stl
Hardware/Gehaeuse/Gehaeuse.iam
Hardware/Gehaeuse/Platine.ipt
Hardware/Verpackung/Boden.ipt
Hardware/Verpackung/Deckel.ipt
Hardware/Verpackung/InlayOben.ipt
Hardware/Verpackung/InlayUnten.ipt
Hardware/Verpackung/Verpackung.iam

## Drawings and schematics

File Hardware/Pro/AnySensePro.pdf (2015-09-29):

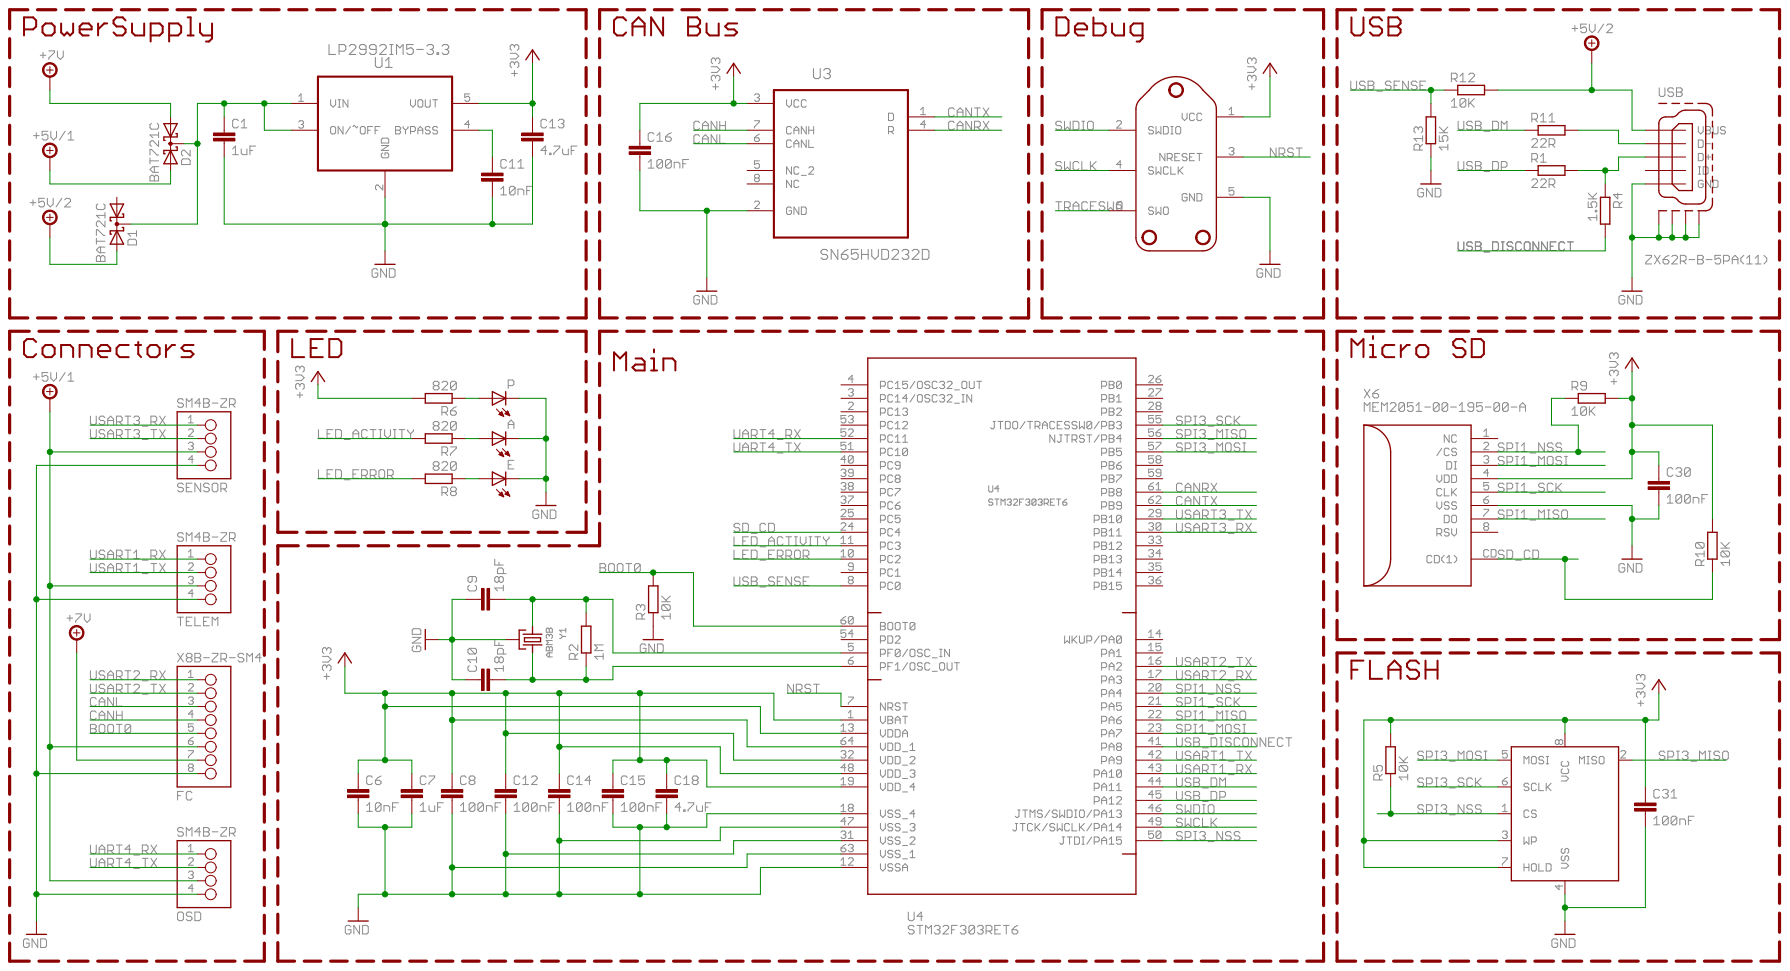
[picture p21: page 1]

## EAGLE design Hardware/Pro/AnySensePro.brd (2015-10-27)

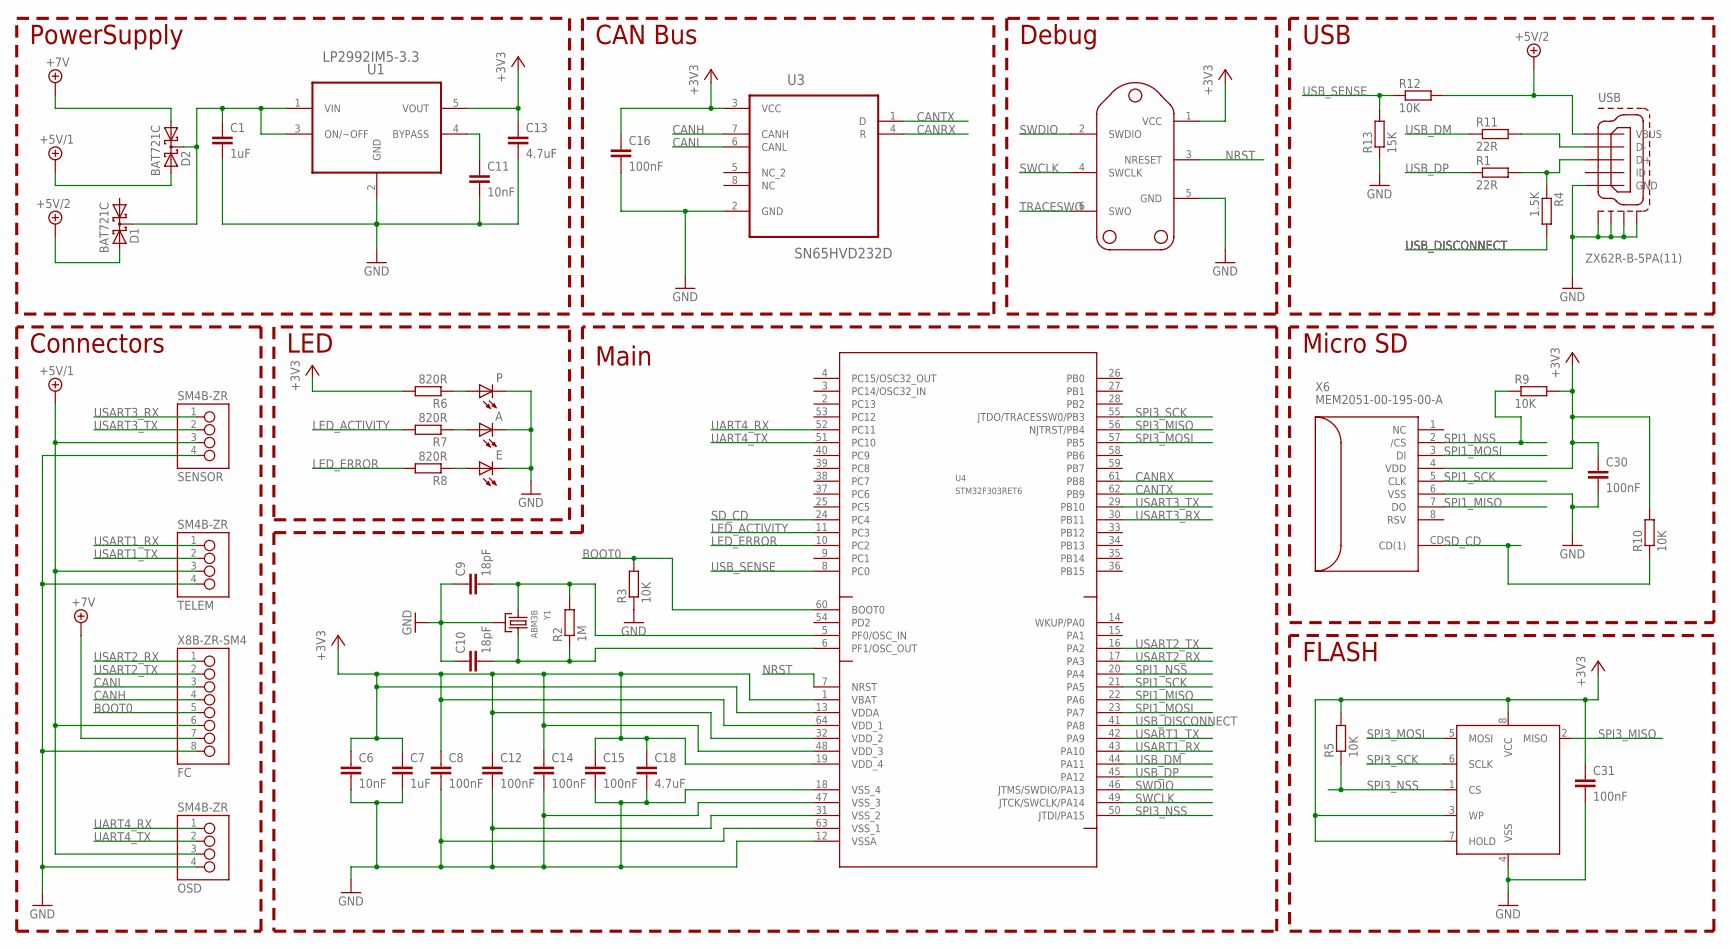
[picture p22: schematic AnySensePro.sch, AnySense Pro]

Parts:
A: LEDCHIP-LED0603; CHIP-LED0603
C1: 1uF; C0603K
C6, C11: 10nF; C0402K
C7: 1uF; C0402K
C8, C12, C14, C15, C16, C30, C31: 100nF; C0402K
C9, C10: 18pF; C0402K
C13, C18: 4.7uF; C0603K
D1, D2: BAT721C; SOT23
E: LEDCHIP-LED0603; CHIP-LED0603
FC: X8B-ZR-SM4; S8B-ZR-SM4
OSD: SM4B-ZR; S4B-ZR-SM4
P: LEDCHIP-LED0603; CHIP-LED0603
R1, R11: 22R; R0402
R2: 1M; R0402
R3, R5, R9, R10, R12: 10K; R0402
R4: 1.5K; R0402
R6, R7, R8: 820R; R0402
R13: 15K; R0402
SENSOR: SM4B-ZR; S4B-ZR-SM4
TELEM: SM4B-ZR; S4B-ZR-SM4
U1: LP2992IM5-3.3; SOT-23
U3: SN65HVD232D; SOIC127P600X175-8N
U4: STM32F303RET6; LQFP64
U6: M25P16VMN6P; M25P16
USB: ZX62R-B-5PA(11)
X6: MEM2051-00-195-00-A; MEM2051
X7: TC2030-IDC-NL; TC2030-IDC
Y1: ABM3B; 5X3.2MM

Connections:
+3V3: C6.1, C7.1, C8.1, C12.1, C13.1, C14.1, C15.1, C16.1, C18.1, C30.1, C31.1, R5.2, R6.2, R9.2, R10.2, U1.5 (VOUT), U3.3 (VCC), U4.1 (VBAT), U4.13 (VDDA), U4.19 (VDD_4), U4.32 (VDD_2), U4.48 (VDD_3), U4.64 (VDD_1), U6.3 (WP), U6.7 (HOLD), U6.8 (VCC), X6.4 (VDD), X7.1 (VCC)
+5V/1: D2.2 (A2), FC.6, OSD.3, SENSOR.3, TELEM.3
+5V/2: D1.2 (A2), R12.2, USB.1 (VBUS)
+7V: D2.1 (A1), FC.7
BOOT0: FC.5, R3.2, U4.60 (BOOT0)
CANH: FC.4, U3.7 (CANH)
CANL: FC.3, U3.6 (CANL)
CANRX: U3.4 (R), U4.61 (PB8)
CANTX: U3.1 (D), U4.62 (PB9)
GND: A.C, C1.2, C6.2, C7.2, C8.2, C9.1, C10.1, C11.2, C12.2, C13.2, C14.2, C15.2, C16.2, C18.2, C30.2, C31.2, E.C, FC.8, OSD.4, P.C, R3.1, R13.1, SENSOR.4, TELEM.4, U1.2 (GND), U3.2 (GND), U4.12 (VSSA), U4.18 (VSS_4), U4.31 (VSS_2), U4.47 (VSS_3), U4.63 (VSS_1), U6.4 (VSS), USB.5 (GND), USB.M1 (S1), USB.M2 (S2), USB.M3 (S3), USB.M4 (S4), X6.6 (VSS), X7.5 (GND), Y1.2 (GND), Y1.4 (GND)
LED_ACTIVITY: R7.2, U4.11 (PC3)
LED_ERROR: R8.2, U4.10 (PC2)
unnamed: C1.1, D1.3 (CC), D2.3 (CC), U1.1 (VIN), U1.3 (ON/~OFF)
unnamed: C10.2, R2.1, U4.6 (PF1/OSC_OUT), Y1.3 (2)
unnamed: C11.1, U1.4 (BYPASS)
unnamed: C9.2, R2.2, U4.5 (PF0/OSC_IN), Y1.1
unnamed: P.A, R6.1
unnamed: A.A, R7.1
unnamed: E.A, R8.1
NRST: U4.7 (NRST), X7.3 (NRESET)
SD_CD: R10.1, U4.24 (PC4), X6.CD (CD(1))
SPI1_MISO: U4.22 (PA6), X6.7 (DO)
SPI1_MOSI: U4.23 (PA7), X6.3 (DI)
SPI1_NSS: R9.1, U4.20 (PA4), X6.2 (/CS)
SPI1_SCK: U4.21 (PA5), X6.5 (CLK)
SPI3_MISO: U4.56 (NJTRST/PB4), U6.2 (MISO)
SPI3_MOSI: U4.57 (PB5), U6.5 (MOSI)
SPI3_NSS: R5.1, U4.50 (JTDI/PA15), U6.1 (CS)
SPI3_SCK: U4.55 (JTDO/TRACESSW0/PB3), U6.6 (SCLK)
SWCLK: U4.49 (JTCK/SWCLK/PA14), X7.4 (SWCLK)
SWDIO: U4.46 (JTMS/SWDIO/PA13), X7.2 (SWDIO)
TRACESWO: X7.6 (SWO)
UART4_RX: OSD.1, U4.52 (PC11)
UART4_TX: OSD.2, U4.51 (PC10)
USART1_RX: TELEM.1, U4.43 (PA10)
USART1_TX: TELEM.2, U4.42 (PA9)
USART2_RX: FC.1, U4.17 (PA3)
USART2_TX: FC.2, U4.16 (PA2)
USART3_RX: SENSOR.1, U4.30 (PB11)
USART3_TX: SENSOR.2, U4.29 (PB10)
USB_D+: R1.2, R4.1, USB.3 (D+)
USB_D-: R11.2, USB.2 (D-)
USB_DISCONNECT: R4.2, U4.41 (PA8)
USB_DM: R11.1, U4.44 (PA11)
USB_DP: R1.1, U4.45 (PA12)
USB_SENSE: R12.1, R13.2, U4.8 (PC0)

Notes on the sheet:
PowerSupply
Connectors
USB
Main
Micro SD
CAN Bus
LED
FLASH
Debug

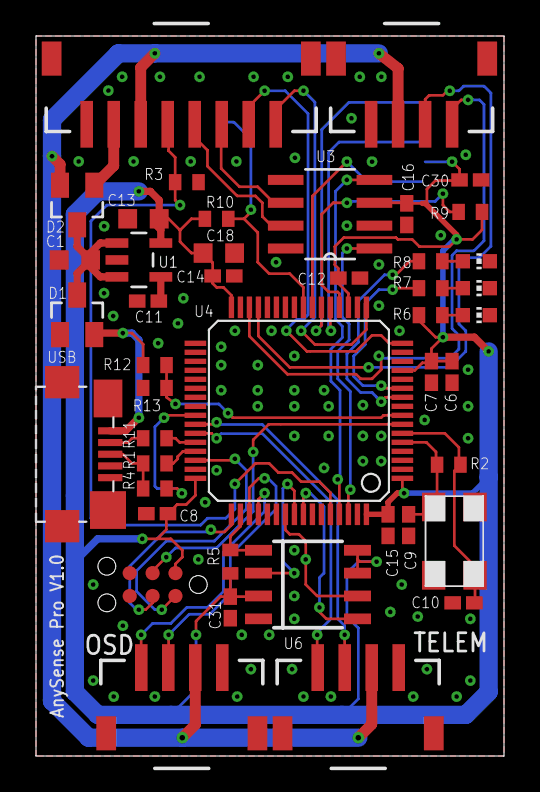
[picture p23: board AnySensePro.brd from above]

Board: 2 copper layers, 26.0 x 40.0 mm, 45 parts (1 on the bottom side), 45 nets.

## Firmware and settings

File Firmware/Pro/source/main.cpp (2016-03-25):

/*
 * main.cpp
 *
 *  Created on: 09.09.2015
 *      Author: cem
 */

#include <scmRTOS.h>
#include <OSAL.h>

#include "Board.h"

#include <Configuration.h>

#include <StorageFlashSPI.h>

#include <TelemetryController.h>
#include <DJIController.h>
#include <FCController.h>
#include <MAVLinkComm.h>
#include <SensorController.h>
#include <USBWorker.h>
#include <System.h>
#include <LoggingController.h>

using namespace App;

TelemetryController telemetryController(Board::Telemetry::USART, Board::Telemetry::TIMER, Board::Telemetry::I2C);
DJIController djiController(Board::FC::CAN);
FCController fcController(Board::FC::USART);
MAVLinkComm mavLinkComm(Board::OSD::USART, MAVLINK_COMM_1);
SensorController sensorController(Board::Sensor::USART);
USBWorker usb_worker(Board::CDCDevice);
System SystemService(Board::LedError, Board::LedActivity);
LoggingController loggingController;

// Process types
typedef OS::process<OS::pr0, 1024> TProc0; //Telemetry Controller
typedef OS::process<OS::pr1, 1024> TProc1; //DJI Controller
typedef OS::process<OS::pr2, 1024> TProc2; //PixHawk, Tarot etc.. Controller
typedef OS::process<OS::pr3, 1024> TProc3; //MAVLink Out Controller
typedef OS::process<OS::pr4, 1024> TProc4; //FrSky Controller
typedef OS::process<OS::pr5, 1024> TProc5; //USB Controller
typedef OS::process<OS::pr6, 1024> TProc6; //System Service
typedef OS::process<OS::pr7, 1024> TProc7; //Logger

// Process objects
TProc0 Proc0;
TProc1 Proc1;
TProc2 Proc2;
TProc3 Proc3;
TProc4 Proc4;
TProc5 Proc5;
TProc6 Proc6;
TProc7 Proc7;

int main()
{
	Board::Init();

	OS::run();
}

namespace OS
{
template<>
OS_PROCESS void TProc0::exec()
{
	Storage::StorageFlashSPI::Mount();
	Storage::StorageFlashSPI::GC(512 * 1024);

	Config.Init();

	SystemService.signalLoaded();

	telemetryController.Init();
	telemetryController.Run();

	//supress compiler warnings
	for (;;)
		;
}

template<>
OS_PROCESS void TProc1::exec()
{
	SystemService.isLoaded();

	djiController.Init();
	djiController.Run();

	//supress compiler warnings
	for (;;)
		;
}

template<>
OS_PROCESS void TProc2::exec()
{
	SystemService.isLoaded();

	fcController.Init();
	fcController.Run();

	//supress compiler warnings
	for (;;)
		OSAL::Timer::SleepSeconds(5);
}

template<>
OS_PROCESS void TProc3::exec()
{
	SystemService.isLoaded();

	mavLinkComm.Init();
	mavLinkComm.Run();

	//supress compiler warnings
	for (;;)
		OSAL::Timer::SleepSeconds(5);
}

template<>
OS_PROCESS void TProc4::exec()
{
	SystemService.isLoaded();

	sensorController.Init();
	sensorController.Run();

	//supress compiler warnings
	for (;;)
		OSAL::Timer::SleepSeconds(5);
}

template<>
OS_PROCESS void TProc5::exec()
{
	SystemService.isLoaded();

	usb_worker.Init();
	usb_worker.Run();

	//supress compiler warnings
	for (;;)
		;
}

template<>
OS_PROCESS void TProc6::exec()
{
	SystemService.Run();

	//supress compiler warnings
	for (;;)
		;
}
template<>
OS_PROCESS void TProc7::exec()
{
	SystemService.isLoaded();

	loggingController.Init();
	loggingController.Run();

	//supress compiler warnings
	for (;;)
		;
}

}

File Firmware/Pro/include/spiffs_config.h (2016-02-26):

/*
 * spiffs_config.h
 *
 *  Created on: Jul 3, 2013
 *      Author: petera
 */

#ifndef SPIFFS_CONFIG_H_
#define SPIFFS_CONFIG_H_

// ----------- 8< ------------
// Following includes are for the linux test build of spiffs
// These may/should/must be removed/altered/replaced in your target
#include <stdio.h>
#include <stdlib.h>
#include <string.h>
#include <stddef.h>
// ----------- >8 ------------

// compile time switches

// Set generic spiffs debug output call.
#ifndef SPIFFS_DBG
#define SPIFFS_DBG(...) //printf(__VA_ARGS__)
#endif
// Set spiffs debug output call for garbage collecting.
#ifndef SPIFFS_GC_DBG
#define SPIFFS_GC_DBG(...) //printf(__VA_ARGS__)
#endif
// Set spiffs debug output call for caching.
#ifndef SPIFFS_CACHE_DBG
#define SPIFFS_CACHE_DBG(...) //printf(__VA_ARGS__)
#endif
// Set spiffs debug output call for system consistency checks.
#ifndef SPIFFS_CHECK_DBG
#define SPIFFS_CHECK_DBG(...) //printf(__VA_ARGS__)
#endif

// Enable/disable API functions to determine exact number of bytes
// for filedescriptor and cache buffers. Once decided for a configuration,
// this can be disabled to reduce flash.
#ifndef SPIFFS_BUFFER_HELP
#define SPIFFS_BUFFER_HELP              0
#endif

// Enables/disable memory read caching of nucleus file system operations.
// If enabled, memory area must be provided for cache in SPIFFS_mount.
#ifndef  SPIFFS_CACHE
#define SPIFFS_CACHE                    1
#endif
#if SPIFFS_CACHE
// Enables memory write caching for file descriptors in hydrogen
#ifndef  SPIFFS_CACHE_WR
#define SPIFFS_CACHE_WR                 1
#endif

// Enable/disable statistics on caching. Debug/test purpose only.
#ifndef  SPIFFS_CACHE_STATS
#define SPIFFS_CACHE_STATS              1
#endif
#endif

// Always check header of each accessed page to ensure consistent state.
// If enabled it will increase number of reads, will increase flash.
#ifndef SPIFFS_PAGE_CHECK
#define SPIFFS_PAGE_CHECK               1
#endif

// Define maximum number of gc runs to perform to reach desired free pages.
#ifndef SPIFFS_GC_MAX_RUNS
#define SPIFFS_GC_MAX_RUNS              5
#endif

// Enable/disable statistics on gc. Debug/test purpose only.
#ifndef SPIFFS_GC_STATS
#define SPIFFS_GC_STATS                 1
#endif

// Garbage collecting examines all pages in a block which and sums up
// to a block score. Deleted pages normally gives positive score and
// used pages normally gives a negative score (as these must be moved).
// To have a fair wear-leveling, the erase age is also included in score,
// whose factor normally is the most positive.
// The larger the score, the more likely it is that the block will
// picked for garbage collection.

// Garbage collecting heuristics - weight used for deleted pages.
#ifndef SPIFFS_GC_HEUR_W_DELET
#define SPIFFS_GC_HEUR_W_DELET          (5)
#endif
// Garbage collecting heuristics - weight used for used pages.
#ifndef SPIFFS_GC_HEUR_W_USED
#define SPIFFS_GC_HEUR_W_USED           (-1)
#endif
// Garbage collecting heuristics - weight used for time between
// last erased and erase of this block.
#ifndef SPIFFS_GC_HEUR_W_ERASE_AGE
#define SPIFFS_GC_HEUR_W_ERASE_AGE      (50)
#endif

// Object name maximum length.
#ifndef SPIFFS_OBJ_NAME_LEN
#define SPIFFS_OBJ_NAME_LEN             (32)
#endif

// Size of buffer allocated on stack used when copying data.
// Lower value generates more read/writes. No meaning having it bigger
// than logical page size.
#ifndef SPIFFS_COPY_BUFFER_STACK
#define SPIFFS_COPY_BUFFER_STACK        (64)
#endif

// Enable this to have an identifiable spiffs filesystem. This will look for
// a magic in all sectors to determine if this is a valid spiffs system or
// not on mount point. If not, SPIFFS_format must be called prior to mounting
// again.
#ifndef SPIFFS_USE_MAGIC
#define SPIFFS_USE_MAGIC                (0)
#endif

// SPIFFS_LOCK and SPIFFS_UNLOCK protects spiffs from reentrancy on api level
// These should be defined on a multithreaded system

// define this to enter a mutex if you're running on a multithreaded system
#ifndef SPIFFS_LOCK
#define SPIFFS_LOCK(fs)
#endif
// define this to exit a mutex if you're running on a multithreaded system
#ifndef SPIFFS_UNLOCK
#define SPIFFS_UNLOCK(fs)
#endif

// Enable if only one spiffs instance with constant configuration will exist
// on the target. This will reduce calculations, flash and memory accesses.
// Parts of configuration must be defined below instead of at time of mount.
#ifndef SPIFFS_SINGLETON
#define SPIFFS_SINGLETON 0
#endif
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

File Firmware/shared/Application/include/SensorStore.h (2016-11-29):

/*
 * SensorStore.h
 *
 *  Created on: 18.09.2015
 *      Author: cem
 */

#ifndef LIBS_INCLUDE_SENSORSTORE_H_
#define LIBS_INCLUDE_SENSORSTORE_H_

#include <stdint.h>
#include <math.h>
#include <DateTime.h>

const uint8_t MAXRCCHANNELS = 16;
const uint8_t MAXCELLS = 24;
const uint8_t MAXMOTOROUTS = 10;

namespace App
{

enum FCType
{
	Unknown = 0, Naza = 1, Phantom = 2, Wookong = 3, A2 = 4, APM = 5, ZYX_M = 6, Align = 7,
};

enum GPSFixType
{
	FixNo = 0, Fix2D = 2, Fix3D = 3, FixDGPS = 4
};

enum FlightMode
{
	Manual = 0, GPS = 1, Failsafe = 2, Attitude = 3
};

enum Sensors
{
	SGPS = 0,
	Vario = 1,
	Voltage = 2,
	GForce = 3,
	Current = 4,
	Consumption = 5,
	Cells = 6,
	Charge = 7,
	Homeing = 8,
	Arming = 9,
	RPM = 10,
};

enum Alarm
{
	AVoltage = 0, ADistance = 1,
};

struct GPSPosition
{
	double Latitude;
	double Longitude;
};

struct Velocity{
	float North;
	float East;
	float Down;
};

class SensorStore
{
private:
	FCType m_FCType = FCType::Unknown;
	GPSFixType m_FixType = GPSFixType::FixNo; //fix type (see GPSFixType)
	uint8_t m_Satellites = 0; //number of satellites
	float m_HDOP = 0; //horizontal dilution of precision
	float m_VDOP = 0; //vertical dilution of precision
	GPSPosition m_PositionCurrent;
	GPSPosition m_PositionHome;
	float m_Speed = 0; //speed in m/s
	float m_CourseOverGround = 0; //course over ground
	Velocity m_velocity;

	Utils::DateTime m_dateTime = Utils::DateTime(14, 6, 13, 18, 0, 0);

	float m_Altitude = 0; //altitude in m (from barometric sensor)
	float m_HomeAltitude = 0; // home altitude from barometric sensor
	float m_VerticalSpeed = 0; //vertical speed (barometric) in m/s (a.k.a. climb speed)

	float m_Heading = 0; //heading in degree

	float m_Pitch = 0; //pitch in degree
	float m_Roll = 0; //roll in degree

	FlightMode m_FlightMode = FlightMode::Failsafe; //flight mode (see mode_t enum)
	uint8_t m_Armed = 0;
	int16_t m_RCChannels[MAXRCCHANNELS] = { 0 }; //RC stick input (-1000~1000), use rcInChan_t enum to index the table
	int16_t m_Throttle = 0;
	uint16_t m_Motors[MAXMOTOROUTS] = { 0 };

	uint16_t m_Battery = 0; //battery voltage in mV
	uint8_t m_CellCount = 0;
	uint16_t m_Cells[MAXCELLS] = { 0 }; //battery voltage in mV
	float m_Current = 0; //current consumption in 0.1 A
	uint32_t m_Capacity = 0; // current capacity (3115mAh)

	uint8_t m_Charge = 0; // percentage of charge (62%)
	uint32_t m_Flightime = 0; //flightime in seconds

	float m_HomeDirection = 0; //home direction in degree
	uint16_t m_HomeDistance = 0; //Home distance in meters

	float m_Temperatur1 = 0;
	float m_Temperatur2 = 0;
	uint32_t m_RPM = 0;

	uint32_t m_Sensors = 0;

	uint32_t m_Alarms = 0;

	uint8_t m_session = 1;

public:
	float GetAltitude() const
	{
		return m_Altitude;
	}

	void SetAltitude(float altitude = 0)
	{
		m_Altitude = altitude;
	}

	uint8_t GetArmed() const
	{
		return m_Armed;
	}

	void SetArmed(uint8_t armed = 0)
	{
		m_Armed = armed;
	}

	uint16_t GetBattery() const
	{
		return m_Battery;
	}

	void SetBattery(uint16_t battery = 0)
	{
		m_Battery = battery;
	}

	uint32_t GetCapacity() const
	{
		return m_Capacity;
	}

	void SetCapacity(uint32_t capacity = 0)
	{
		m_Capacity = capacity;
	}

	uint8_t GetCellCount() const
	{
		return m_CellCount;
	}

	void SetCellCount(uint8_t cellCount = 0)
	{
		m_CellCount = cellCount;
	}

	const uint16_t* GetCells() const
	{
		return m_Cells;
	}

	uint16_t GetCell(uint8_t cell) const
	{
		if (cell >= m_CellCount)
			return 0;

		return m_Cells[cell];
	}

	uint16_t GetCellLowest()
	{
		uint16_t cell = m_Cells[0];
		for (uint8_t i = 1; i < m_CellCount; i++)
		{
			if (m_Cells[i] < cell)
				cell = m_Cells[i];
		}
		return cell;
	}

	uint8_t GetCharge() const
	{
		return m_Charge;
	}

	void SetCharge(uint8_t charge = 0)
	{
		m_Charge = charge;
	}

	float GetCourseOverGround() const
	{
		return m_CourseOverGround;
	}

	void SetCourseOverGround(float courseOverGround = 0)
	{
		m_CourseOverGround = courseOverGround;
	}

	float GetCurrent() const
	{
		return m_Current;
	}

	void SetCurrent(float current = 0)
	{
		m_Current = current;
	}

	const Utils::DateTime& GetDateTime() const
	{
		return m_dateTime;
	}

	void SetDateTime(uint16_t year, uint8_t month, uint8_t day, uint8_t hour, uint8_t min, uint8_t sec)
	{
		m_dateTime.SetYear(year);
		m_dateTime.SetMonth(month);
		m_dateTime.SetDay(day);
		m_dateTime.SetHour(hour);
		m_dateTime.SetMinute(min);
		m_dateTime.SetSecond(sec);
	}

	void SetDateTime(Utils::DateTime& dateTime)
	{
		m_dateTime = dateTime;
	}

	FCType GetFCType() const
	{
		return m_FCType;
	}

	void SetFCType(FCType fcType = FCType::Unknown)
	{
		m_FCType = fcType;
	}

	GPSFixType GetFixType() const
	{
		return m_FixType;
	}

	void SetFixType(GPSFixType fixType = GPSFixType::FixNo)
	{
		m_FixType = fixType;
	}

	uint8_t IsGPSOK() const
	{
		return m_FixType >= GPSFixType::Fix3D;
	}

	uint32_t GetFlightime() const
	{
		return m_Flightime;
	}

	void SetFlightime(uint32_t flightime = 0)
	{
		m_Flightime = flightime;
	}

	FlightMode GetFlightMode() const
	{
		return m_FlightMode;
	}

	void SetFlightMode(FlightMode flightMode = FlightMode::Failsafe)
	{
		m_FlightMode = flightMode;
	}

	float GetHdop() const
	{
		return m_HDOP;
	}

	void SetHdop(float hdop = 0)
	{
		m_HDOP = hdop;
	}

	float GetHeading() const
	{
		return m_Heading;
	}

	void SetHeading(float heading = 0)
	{
		m_Heading = heading;
	}

	float GetHomeAltitude() const
	{
		return m_HomeAltitude;
	}

	void SetHomeAltitude(float homeAltitude = 0)
	{
		m_HomeAltitude = homeAltitude;
	}

	float GetRelativeAltitude() const
	{
		return m_Altitude - m_HomeAltitude;
	}

	float GetPitch() const
	{
		return m_Pitch;
	}

	void SetPitch(float pitch = 0)
	{
		m_Pitch = pitch;
	}

	const GPSPosition& GetPositionCurrent() const
	{
		return m_PositionCurrent;
	}

	void SetPositionCurrent(double latitude, double longitude)
	{
		m_PositionCurrent.Latitude = latitude;
		m_PositionCurrent.Longitude = longitude;
	}

	const GPSPosition& GetPositionHome() const
	{
		return m_PositionHome;
	}

	void SetPositionHome(double latitude, double longitude)
	{
		m_PositionHome.Latitude = latitude;
		m_PositionHome.Longitude = longitude;
	}
	void SetPositionHome()
	{
		m_PositionHome.Latitude = m_PositionCurrent.Latitude;
		m_PositionHome.Longitude = m_PositionCurrent.Longitude;
	}
	void SetPositionHomeClear()
	{
		m_PositionHome.Latitude = 0;
		m_PositionHome.Longitude = 0;
	}
	uint8_t IsPositionHomeSet()
	{
		return m_PositionHome.Latitude != 0 && m_PositionHome.Longitude != 0;
	}

	void SetVelocity(float north, float east, float down){
		m_velocity.North = north;
		m_velocity.East = east;
		m_velocity.Down = down;
	}
	const Velocity& GetVelocity() const {
		return m_velocity;
	}

	void SetRCChannels(int16_t* value, uint8_t count)
	{
		for (uint8_t channel = 0; channel < count; channel++)
			m_RCChannels[channel] = value[channel];
	}
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

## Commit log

2015-09-03 Initial Hardware commit
    [AnySensePro.brd, AnySensePro.sch, BOM.csv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]
2015-09-03 Order Codes added
    [AnySensePro.brd, AnySensePro.sch, BOM.csv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]
2015-09-04 Kalkulation, Datasheet
    [Kalkulation.xlsx]
2015-09-09 Kalkulation, Dokumentation
    [Kalkulation.xlsx]
2015-09-28 BLE Modul
    [BLE-Modul.sch]
2015-09-28 Hardware redesign
    [AnySensePro.brd, AnySensePro.sch]
2015-09-28 BlueNRG driver
2015-09-28 USB Driver and CDC, MSC support
2015-09-28 Hardware Libraries added and Calculation updated
    [Kalkulation.xlsx, Requirements.xlsx]
2015-09-28 Windows USB driver
2015-09-29 AnySense Pro V1.1
    [AnySensePro.brd, AnySensePro.sch]
2015-09-29 AnySense Pro Anfrage pcb-pool.com
    [AnySensePro.brd]
2015-09-30 Eurocircuits Order
    [AnySensePro.brd]
2015-10-02 SPI SDCard Library completed (stable)
2015-10-08 Farnell OC's updated and paste pad reduction removed.
    [AnySensePro.brd, AnySensePro.sch, BOM.csv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]
2015-10-27 Final HW Design
    [AnySensePro.brd, Kalkulation.xlsx]
2015-10-27 lot changes
    [Benchmark MicroSD.xlsx, Configuration.h, Test Telemetry.xlsx]
2015-10-27 USBWorker: Pool/Queue replaced with OSAL::Channel
    [USBWorker.cpp]
2016-02-13 Simplify USB CDC Device
2016-02-25 Folding Interrupt Forwarding
2016-02-29 boot loader remove delay on start (hold boot loader time as short as possible)
    [main.c]
2016-03-01 removed format of flash drive while mounting
2016-03-01 Driver installation Package, Bootstrapper and prerequisite
2016-03-02 Remove grouping of device change events for faster reconnect
2016-03-04 Sensor Store Set cells
2016-03-04 Telemetry analysing
    [CANBus Analyse.xlsx, Test Telemetry.xlsx]
2016-03-04 start device polling async
2016-03-05 SPI Flash Autorelease file and read file
2016-03-05 Load, Save Configuration
    [Configuration.h]
2016-03-05 AnySense Studio: Debug log printing
2016-03-05 Filter polling serial devices
2016-03-06 Sensor Store: save available Sensors
2016-03-06 increase threads and re-prioritize workers
2016-03-06 Thread Memory space corrected
    [main.cpp]
2016-03-06 Configuration Changed Handler
    [Configuration.h]
2016-03-06 Configuration Protocol and UI
    [Configuration.h]
2016-03-06 Notify configuration changed
    [Configuration.h]
2016-03-07 BugFix: usb device name retrieval
2016-03-07 configuration structure corrected
    [Configuration.h]
2016-03-08 Protocol dependent settings
    [Configuration.h]
2016-03-08 MAVLink Battery pack extended
2016-03-09 signaling in interrupt modified
2016-03-09 telemetry HoTT finished (unstable)
    [TelemetryHoTT.h]
2016-03-12 Firmware: SensorController created, initial commit frsky sensor
2016-03-14 FrSky lipo data structure added
2016-03-14 FrSky Sensor polling finished
2016-03-17 HAL: Timer added
2016-03-17 Timer for Telemetry Port
2016-03-17 Prioritize Interrupts
2016-03-18 AnySense Studio, Driver and installer signing
2016-03-22 Bug on configuration changed
    [Configuration.cpp]
2016-03-22 BugFix Futaba Telemetry configuration
    [TelemetryFutaba.h]
2016-03-22 Telemetry Jeti sign fix
    [TelemetryJeti.h]
2016-03-22 Telemetry Jeti consumption decimal point corrected
    [TelemetryJeti.cpp]
2016-03-22 Flight session and permanent flight number counter
    [Configuration.h]
2016-03-22 DateTime Util class added and SensorStore::GPSTime replaced
    [Board.cpp, SensorStore.h, TelemetryHoTT.h]
2016-03-23 configuration struct reserved bytes changed to union
    [Configuration.h]
2016-03-25 SensorData.Capacity changed to 32bit
2016-03-25 HAL i2c
2016-03-25 leave HSI enabled for i2c usage
2016-03-25 passing i2c interface to telemetry controller
2016-03-31 BugFix: Jeti Telemetry descriptions was transferred, even if the channel was disabled
    [TelemetryJeti.cpp]
2016-04-06 reorganize folder structure
    [Benchmark MicroSD.xlsx, CANBus Analyse.xlsx, Test Telemetry.xlsx]
2016-04-19 Voltage, Distance Alarm
    [Configuration.h]
2016-06-01 Jeti RPM Sensor added
2016-06-22 FC Align Initial commit
    [Requirements.xlsx]
2016-07-15 Gehäuse initial version
    [Boden.ipt, Deckel.ipt, Gehäuse.iam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]
2016-07-19 Gehäuse first print
    [Boden.stl, Boden.stp, Deckel.ipt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]
2016-07-22 Gehäuse V2
    [Boden.ipt, Boden.stl, Boden.stp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]
2016-07-27 Gehäuse V3
    [Boden.ipt, Boden.stl, Boden.stp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]
2016-08-01 Gehäuse V4
    [Boden.ipt, Boden.stl, Boden.stp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]
2016-08-04 Gehäuse V5: Schnapper verstärkt
    [Deckel.ipt, Gehäuse.iam]
2016-11-29 AnySense Verpackung
    [Boden.ipt, Deckel.ipt, InlayOben.ipt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]
2016-11-29 DJI save velocity
2022-04-23 rename umlaute
    [Boden.ipt, Boden.stl, Boden.stp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]
2022-04-24 add license and some readme
    [Gehaeuse.iam]
